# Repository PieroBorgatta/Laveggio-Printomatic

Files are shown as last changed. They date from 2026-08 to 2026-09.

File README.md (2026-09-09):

<p align="center">
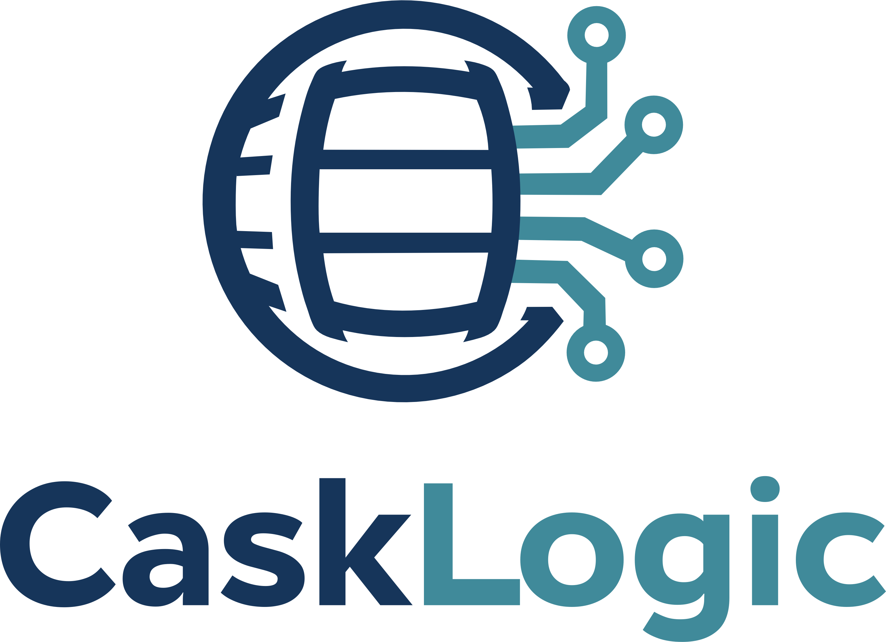
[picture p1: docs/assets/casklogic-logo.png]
CaskLogic
  
</p>

<h1 align="center">CaskLogic PesaLink</h1>

<p align="center">
  Digitalizzazione non invasiva della pesa meccanica Laveggio Printomatic del 1965.<br>
  Sistema non fiscale, destinato esclusivamente all'uso interno.
</p>

<p align="center">
  
  
  
  
</p>

<p align="center">
  <a href="#-panoramica">Panoramica</a> ·
  <a href="#-funzioni">Funzioni</a> ·
  <a href="#-calibrazione-guidata">Calibrazione</a> ·
  <a href="#-hardware">Hardware</a> ·
  <a href="#-avvio-rapido">Avvio rapido</a> ·
  <a href="#-sicurezza">Sicurezza</a> ·
  <a href="#-documentazione">Documentazione</a>
</p>

---

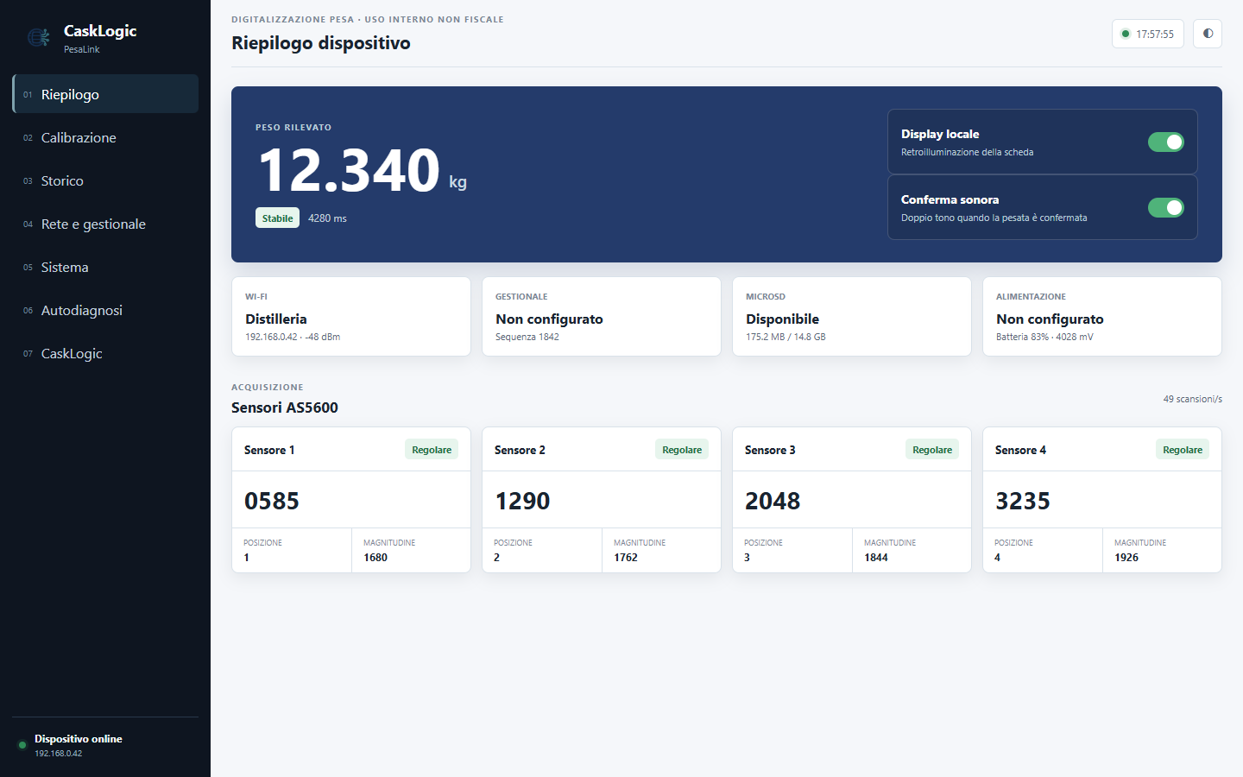
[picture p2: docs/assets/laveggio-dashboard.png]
Dashboard CaskLogic PesaLink per la pesa Laveggio Printomatic


## 🧭 Panoramica

CaskLogic PesaLink legge le quattro manopole meccaniche della pesa Laveggio
Printomatic attraverso sensori magnetici AS5600, ricostruisce il peso e conserva lo storico su
microSD. La Waveshare ESP32-S3-Touch-LCD-2.8 espone un display capacitivo
240×320 e un portale web CaskLogic per
calibrazione, diagnostica, manutenzione e integrazione con il gestionale.

Il sistema non altera la meccanica originale e mantiene sempre disponibile la
lettura locale. Il gestionale CaskLogic rimane un componente separato: questo
repository contiene firmware, simulatore, contratto di integrazione e
documentazione hardware.

> [!WARNING]
> **Digitalizzazione della pesa a uso interno, non fiscale.** Il peso acquisito
> ha finalità informative e operative interne; non sostituisce uno strumento di
> pesatura omologato né una misura valida per transazioni commerciali, adempimenti
> fiscali o verifiche metrologiche legali.

> [!IMPORTANT]
> La versione 2.2.7 mantiene acquisizione e invio prioritario separati dalle
> funzioni accessorie, include il collaudo completo della bascula e ordina i
> grafici cronologicamente. Uptime, temperature CPU e QMI8658 e frequenza CPU fissa
> sono visibili nella pagina Sistema. La rilevazione della chiusura resta configurabile e parte
> disattivata, ma è stata collaudata sul montaggio installato.

## Novità 2.2.7

- Grafici diagnostici ordinati dal campione più vecchio a sinistra al più recente a destra.
- Uptime, istante di avvio, temperatura interna della CPU e temperatura del QMI8658 evidenziati nella pagina Sistema.
- Frequenza CPU nuovamente fissa a 240 MHz; rimossi selettore, endpoint e preferenza dei profili ridotti.
- Export completo dei log eseguito in un task a bassa priorità e trasferito a blocchi, senza trattenere il portale.
- Storico iniziale ridotto alle cinque pesate più recenti e lettura della coda SD limitata a 32 KB.
- Riavvio programmabile, disattivabile, giornaliero oppure settimanale con giorno e ora configurabili.
- Interfaccia e documentazione allineate al collaudo completato dell'impianto.

## Novità 2.1.3

- Il conto alla rovescia del ripristino riattiva sempre controller LCD e retroilluminazione, anche con display spento manualmente o per inattività.
- Il ripristino di fabbrica a 10 secondi è disponibile esclusivamente con BOOT.
- Il tasto alimentazione PWR gestisce esclusivamente lo spegnimento, senza conto alla rovescia né funzione di ripristino.

## Novità 2.1.1

- Il portale di prima configurazione resta attivo mentre il dispositivo prova la rete scelta, senza riavvio immediato.
- Rilevamento captive portal per iPhone, Android e Windows; scansione iniziale più breve e nessun channel hopping durante l'uso dell'AP.
- Spegnimento completo del display configurabile dopo un numero di minuti, con riattivazione tramite touch o BOOT.
- Campi data dello storico contenuti correttamente nella larghezza disponibile su smartphone.
- Riavvio manuale da interfaccia web verificato tramite test automatico.

## Novità 2.1.0

- Letture nominali a 50 Hz su task dedicato; HTTPS e MQTT delle pesate separati da portale, storico e heartbeat.
- RTC UTC per riavvii senza rete, dopo la prima sincronizzazione; origine dell'ora esplicita.
- Stati distinti: lettura stabile, salvataggio SD, ricezione HTTPS e pubblicazione MQTT.
- Ordine dei sensori configurabile, controlli di rumore e sovrapposizione, calibrazione NVS con revisione e CRC.
- Rilevazione collaudata di colpo/quiete per la chiusura della bascula: soglie, tempi e modalità di sola osservazione.
- Luminosità, attenuazione, avvisi batteria e gestione del tasto di alimentazione.

[Guida completa, impostazioni e procedura di prova](docs/reliability-2.1.md).

## ✦ Funzioni

| Area | Funzioni disponibili |
| --- | --- |
| **Acquisizione** | Quattro AS5600 isolati tramite PCA9546/TCA9546A, calibrazione di dieci posizioni per manopola, tolleranza, isteresi e stabilità |
| **Interfacce** | Display e portale con la stessa palette interna blu `#243b6b`, fondo `#f5f7fa`, pannelli bianchi e testo antracite; boot di 10 secondi con logo centrale e barra; aggiornamenti live incrementali |
| **Storico** | Prime 5 pesate al caricamento, export coerente con i filtri, file NDJSON settimanali e retention configurabile su microSD FAT32, incluse SDXC da 128 GB |
| **Autodiagnosi** | Test di sensori, microSD, batteria, touch, speaker, IMU, RTC, Wi-Fi, DNS, gestionale e heap; grafici 24 ore e contatori di errore |
| **Audio** | Doppio tono asincrono su PCM5101 dopo il salvataggio SD di una nuova pesata; avviso distinto per errori, disabilitabile e persistente; volume 0–100% regolabile dal portale; il test web emette un singolo bip breve, azzera il DMA e disattiva fisicamente le linee I2S |
| **Assistenza** | Pacchetto ZIP anonimizzato con stato, diagnostica, log e registro aggiornamenti |
| **Rete** | DHCP o IP statico, scansione Wi-Fi e access point captive stabile `LP-PW_casklogic-192_168_4_1` |
| **Integrazione** | HTTPS/mTLS, MQTT TLS opzionale, heartbeat, eventi firmati HMAC-SHA256, metriche Prometheus e configurazione remota versionata |
| **Aggiornamenti** | OTA firmato ECDSA-P256, doppia partizione, validazione al riavvio, rollback e registro degli esiti |

Il firmware non usa una coda persistente per gli eventi verso il gestionale e
non trasforma la microSD in un NAS.

## 🖥️ Pagine del portale

| Pagina | Cosa permette di fare |
| --- | --- |
| **Riepilogo** | Leggere peso, stabilità, sensori, Wi-Fi, microSD, alimentazione e batteria. Display e conferma sonora hanno interruttori indipendenti e persistenti; il volume 0–100% vale sia per la conferma sia per `Prova bip`. |
| **Calibrazione** | Associare a ciascuna manopola le dieci posizioni `0–9`, salvare il valore magnetico e regolare moltiplicatore, tolleranza e isteresi senza ricompilare il firmware. |
| **Storico** | Consultare soltanto le 20 pesate più recenti al primo accesso, filtrare e ordinare ogni colonna ed esportare esattamente il risultato dei filtri attivi. |
| **Rete e gestionale** | Cercare reti Wi-Fi, scegliere DHCP o IP statico, configurare HTTPS/mTLS, HMAC, heartbeat, MQTT TLS e sincronizzazione controllata dal gestionale. |
| **Sistema** | Gestire display, speaker, NTP/RTC, credenziali, retention, batteria, log, riavvio e OTA firmato. Swipe e barra touch cambiano pagina; BOOT breve resta disponibile e la pressione continua mostra il ripristino da 10 secondi. |
| **Autodiagnosi** | Eseguire prove attive, controllare errori e magneti dei sensori, osservare i grafici giornalieri e scaricare un pacchetto assistenza anonimizzato. |
| **CaskLogic** | Consultare contatti di assistenza, titolarità, crediti, versione e informazioni legali del dispositivo. |

## 🎛️ Calibrazione guidata

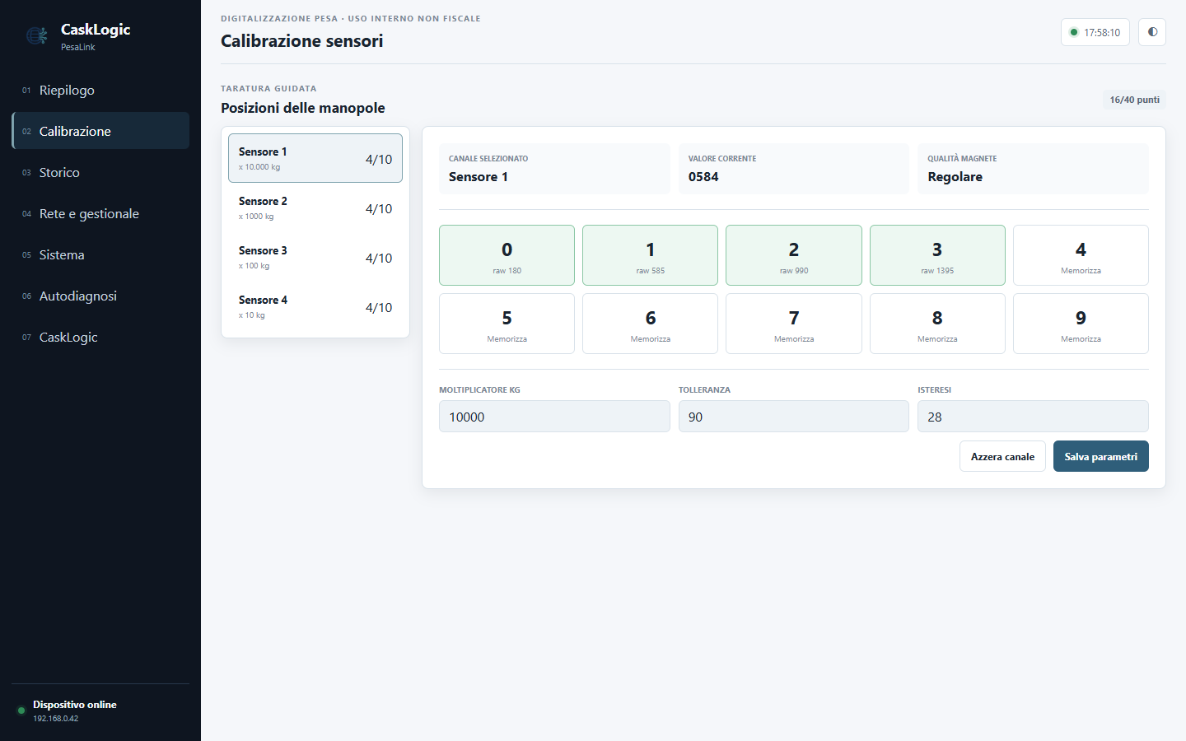
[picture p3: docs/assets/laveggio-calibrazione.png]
Calibrazione dei quattro sensori


Ogni sensore rappresenta una cifra della pesa. I quattro moltiplicatori
collaudati sono `10.000`, `1.000`, `100` e `10 kg`.

### Procedura

1. Selezionare il sensore corrispondente alla manopola da calibrare.
2. Portare fisicamente la manopola sulla cifra `0`.
3. Verificare che **Qualità magnete** indichi `Regolare` e che il valore corrente
   sia stabile.
4. Premere il riquadro `0 · Memorizza`: il firmware salva in NVS il valore
   grezzo AS5600 letto in quell'istante.
5. Ripetere la stessa operazione per le posizioni da `1` a `9`.
6. Impostare moltiplicatore, tolleranza e isteresi, quindi premere
   **Salva parametri**.
7. Ripetere la procedura per tutti e quattro i sensori, fino a raggiungere
   `40/40 punti`.

Un singolo punto può essere rimemorizzato in qualsiasi momento cliccando di
nuovo la relativa cifra. **Azzera canale** elimina soltanto i dieci punti del
sensore selezionato e richiede conferma; non modifica gli altri canali.

| Parametro | Effetto |
| --- | --- |
| **Moltiplicatore kg** | Determina il contributo della cifra al peso totale: `posizione × moltiplicatore`. |
| **Tolleranza** | Distanza angolare massima tra lettura corrente e punto memorizzato affinché la cifra sia considerata valida. |
| **Isteresi** | Mantiene la posizione precedente entro una fascia aggiuntiva, evitando passaggi continui fra due cifre causati da vibrazioni o gioco meccanico. |
| **Finestra di stabilità** | Tempo durante il quale tutte le cifre devono restare invariate prima che la misura diventi una nuova pesata stabile. |

Il confronto usa la distanza circolare dell'AS5600, quindi gestisce
correttamente anche il passaggio fra `4095` e `0`. Se un magnete è assente,
troppo debole, troppo forte, fuori tolleranza o non calibrato, l'intera misura
rimane non valida e non viene registrata come nuova pesata.

## ⚙️ Dalla lettura alla pesata

1. Il multiplexer interroga continuamente i quattro AS5600 a `100 kHz`.
2. Ogni valore grezzo viene confrontato con i dieci punti del proprio canale.
3. Tolleranza e isteresi determinano la cifra riconosciuta senza oscillazioni.
4. Le quattro cifre vengono moltiplicate e sommate per ottenere i chilogrammi.
5. La combinazione deve restare invariata per la finestra di stabilità.
6. Una combinazione valida, stabile e diversa dalla precedente genera una
   nuova riga nello storico e un evento firmato verso il gestionale. Una chiusura rilevata può aggiungere un evento di completamento.

La microSD conserva lo storico indipendentemente dalla connessione di rete, ma
non viene usata come coda automatica di reinvio.

## 📊 Autodiagnosi

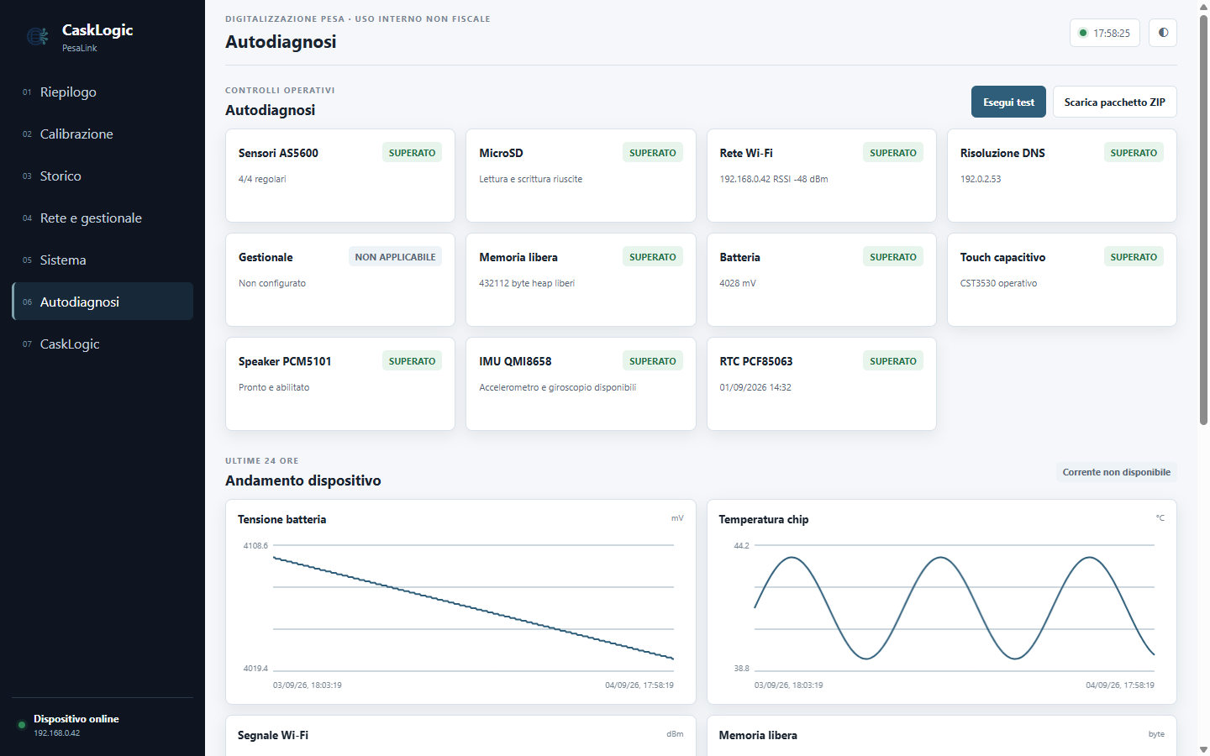
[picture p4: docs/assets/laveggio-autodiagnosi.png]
Autodiagnosi CaskLogic PesaLink


La corrente assorbita è indicata come non disponibile perché la scheda non
integra un sensore amperometrico. Tensione batteria, temperatura della scheda,
RSSI e memoria libera sono invece registrabili senza aggiungere altre schede.

## 🧩 Architettura

```mermaid
flowchart LR
    A[4 manopole] --> B[4 sensori AS5600]
    B --> C[PCA9546 Adafruit 5663]
    C --> D[ESP32-S3 Touch LCD 2.8]
    D --> E[ST7789 + CST3530/CST328]
    D --> F[MicroSD SDMMC]
    D --> G[Portale web CaskLogic]
    D -->|HTTPS / mTLS| H[Gestionale]
    D -->|MQTT TLS opzionale| H
    I[LiPo 1S] --> D
    D --> K[PCM5101 + 2 speaker]
    D --> L[QMI8658 + PCF85063]
    M[Antenna Wi-Fi 2,4 GHz] -->|SMA + pigtail IPEX1| D
```

## 🔩 Hardware

| Componente | Quantità | Riferimento |
| --- | ---: | --- |
| Waveshare ESP32-S3-Touch-LCD-2.8, 16 MB flash / 8 MB PSRAM | 1 | [Documentazione ufficiale](https://docs.waveshare.com/ESP32-S3-Touch-LCD-2.8) |
| Adafruit PCA9546 compatto a 4 canali, cod. 5663 (compatibile TCA9546A) | 1 | [Amazon.it · B0BSF13WD7](https://www.amazon.it/dp/B0BSF13WD7) |
| Kit moduli AS5600 a 12 bit con magneti | 1 kit | [Amazon.it · B0FH1Y3GLG](https://www.amazon.it/dp/B0FH1Y3GLG) |
| Cavetti micro JST-SH 1,0 mm, 4 pin | 1 confezione | [Amazon.it · B0BNCHC5Q4](https://www.amazon.it/dp/B0BNCHC5Q4) |
| Pigtail IPEX-1/U.FL verso SMA femmina, 15 cm | 1 confezione da 5 | [Amazon.it · B07YBYMBSV](https://www.amazon.it/dp/B07YBYMBSV) |
| Antenna Wi-Fi 2,4 GHz 2 dBi, SMA maschio | 1 confezione da 2 | [Amazon.it · B0CR5JPMNX](https://www.amazon.it/dp/B0CR5JPMNX) |
| Cavo dati Lapp LiYY 4 × 0,14 mm², nero | 1 spezzone da 10 m | [Amazon.it · B0C69CJYZT](https://www.amazon.it/dp/B0C69CJYZT) |
| Kit viti a macchina svasate nere M2 / M2,5 / M3, acciaio al carbonio | 1 kit da 500 | [Amazon.it · B0D1N4D5ZR](https://www.amazon.it/dp/B0D1N4D5ZR) |
| Kit da 360 inserti filettati a caldo in ottone M2 / M2,5 / M3 / M4 / M5 / M6 | 1 kit | [Amazon.it · B0G1H5QBSF](https://www.amazon.it/dp/B0G1H5QBSF); utilizzati 8 inserti M5 × 6 mm |
| Grani con punta M5 × 12 mm, acciaio inox A2, esagono incassato, DIN 914 / ISO 4027 | 8 (2 per supporto) | [Amazon.it · B0BZD8WXDQ](https://www.amazon.it/dp/B0BZD8WXDQ); confezione da 20 |
| Speaker 8 Ω 2 W 2030 | 2 | Inclusi con la scheda Waveshare |
| Batteria LiPo 803040, 3,7 V, 1000 mAh, protetta | 1 | [Amazon.it · B0G5NM9YJ4](https://www.amazon.it/dp/B0G5NM9YJ4); connettore JST 1,25 mm, polarità da verificare |
| SanDisk Extreme microSDXC 128 GB, A2 / U3 / V30 | 1 | [Amazon.it · B07FCMKK5X](https://www.amazon.it/dp/B07FCMKK5X); montata e verificata in lettura/scrittura |

Ciascuno dei quattro supporti dei sensori AS5600 utilizza due inserti
filettati a caldo M5 × 6 mm e due grani con punta M5 × 12 mm. Il montaggio
completo impiega otto inserti e otto grani.

### Foto del prototipo

<p align="center">
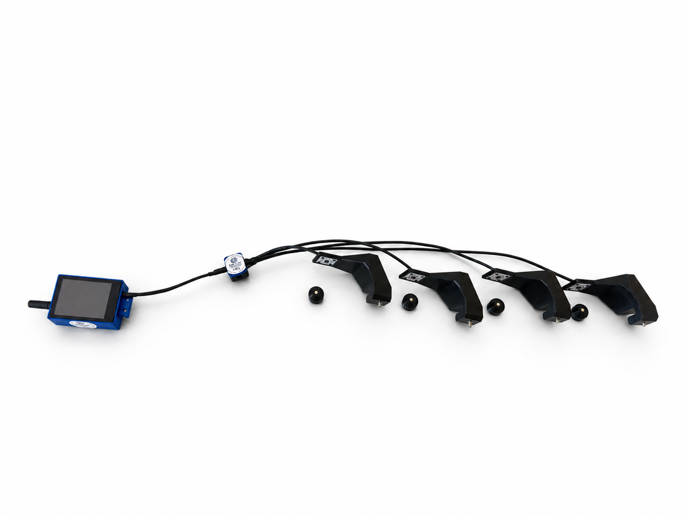
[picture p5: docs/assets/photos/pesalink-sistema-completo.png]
Sistema CaskLogic PesaLink completo
  
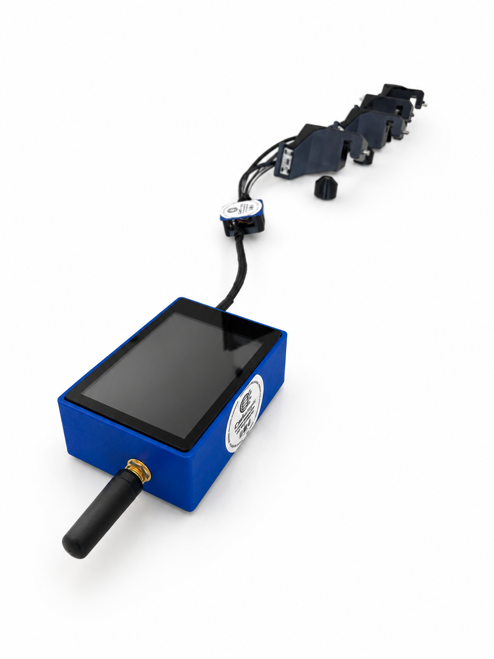
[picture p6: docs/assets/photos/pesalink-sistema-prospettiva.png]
Sistema PesaLink in prospettiva
  
</p>
<p align="center">
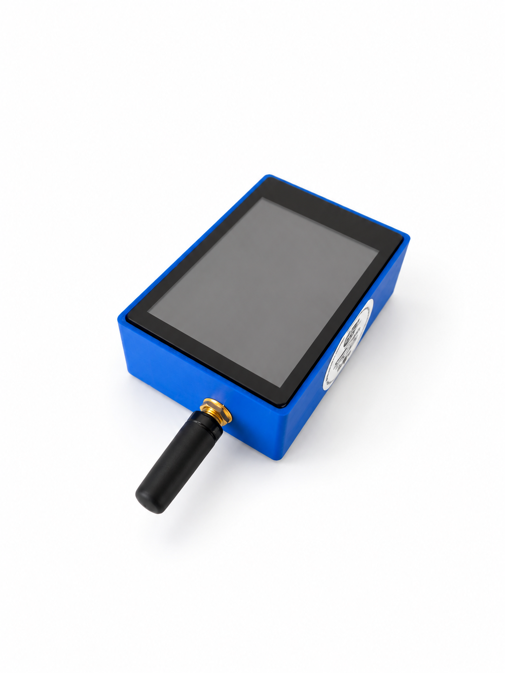
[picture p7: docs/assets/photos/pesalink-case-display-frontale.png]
Case del display visto frontalmente
  
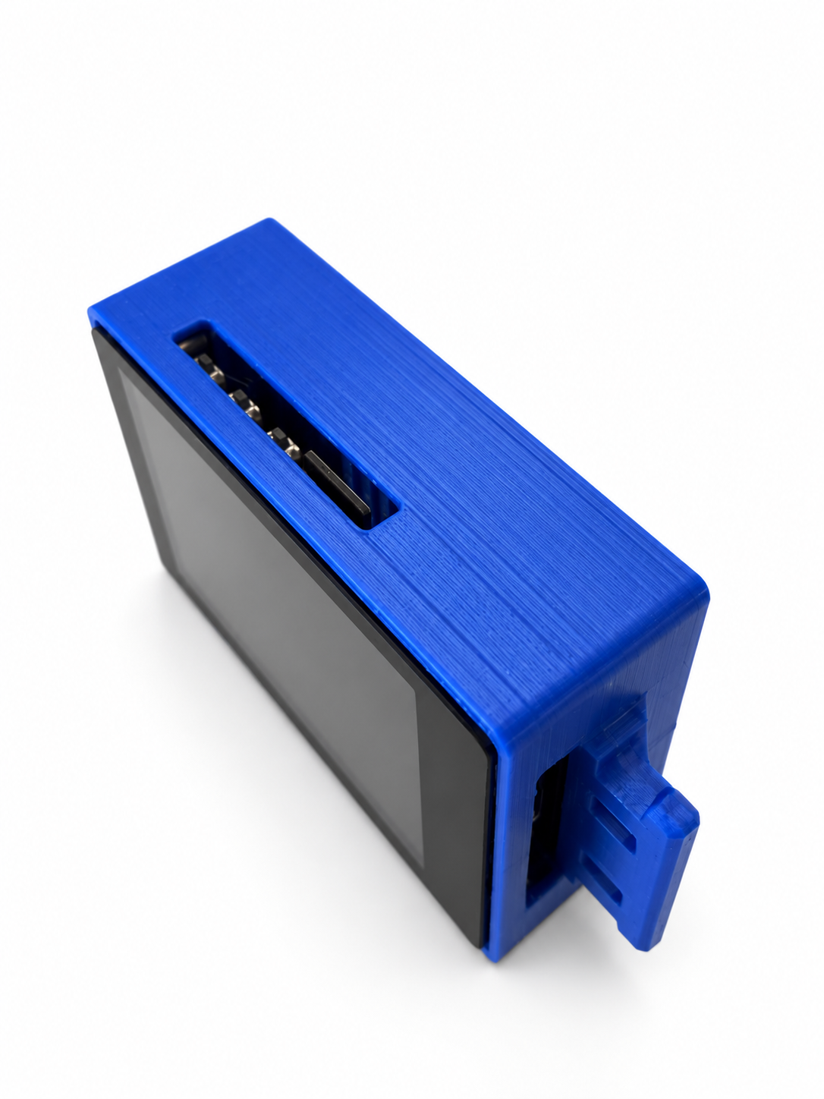
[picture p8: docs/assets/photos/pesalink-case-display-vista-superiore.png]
Case del display visto dall'alto
  
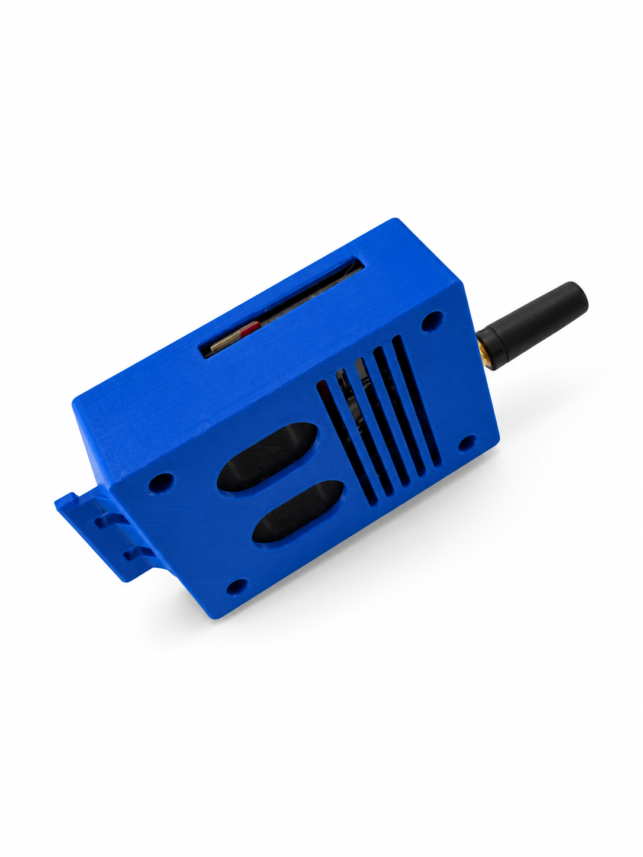
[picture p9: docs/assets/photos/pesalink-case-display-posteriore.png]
Case del display visto posteriormente
  
</p>
<p align="center">
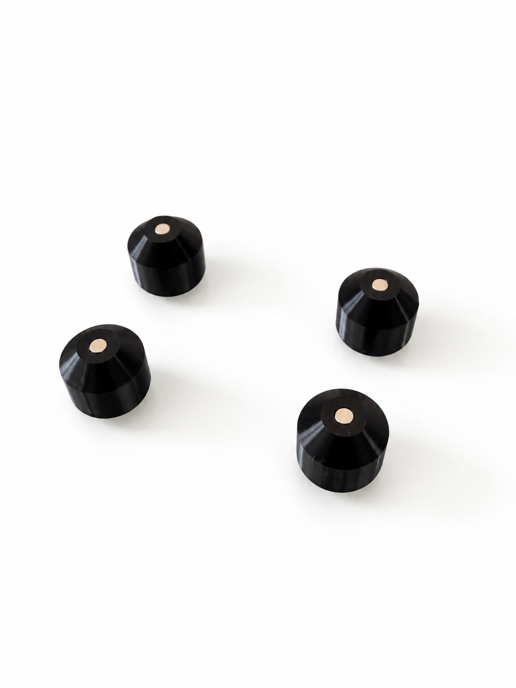
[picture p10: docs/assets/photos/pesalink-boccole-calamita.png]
Boccole stampate per le calamite
  
</p>

### Foto dell'installazione completata

<p align="center">
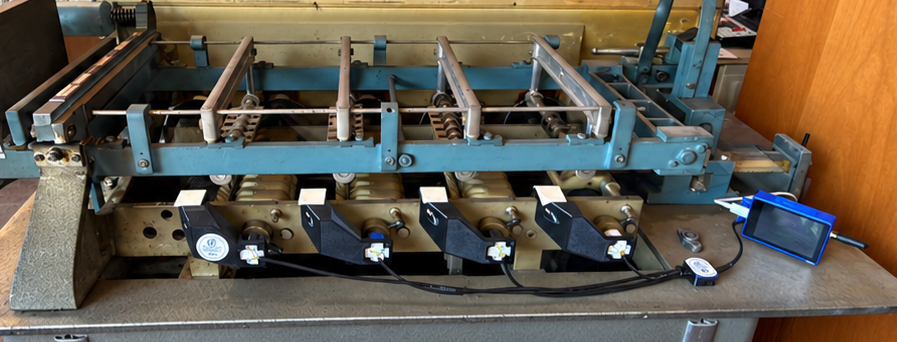
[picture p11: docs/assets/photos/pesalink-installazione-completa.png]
Installazione completa dei quattro sensori PesaLink e del gateway sulla bascula
  
</p>
<p align="center">
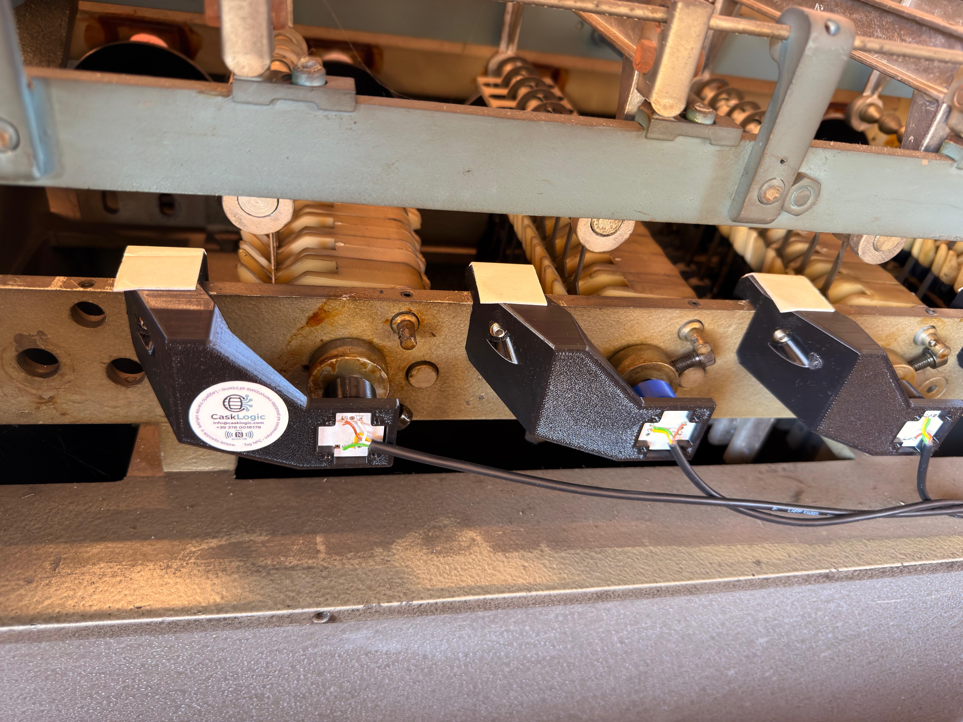
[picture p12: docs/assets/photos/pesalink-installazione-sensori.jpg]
Dettaglio dei supporti e dei sensori PesaLink installati sulla bascula
  
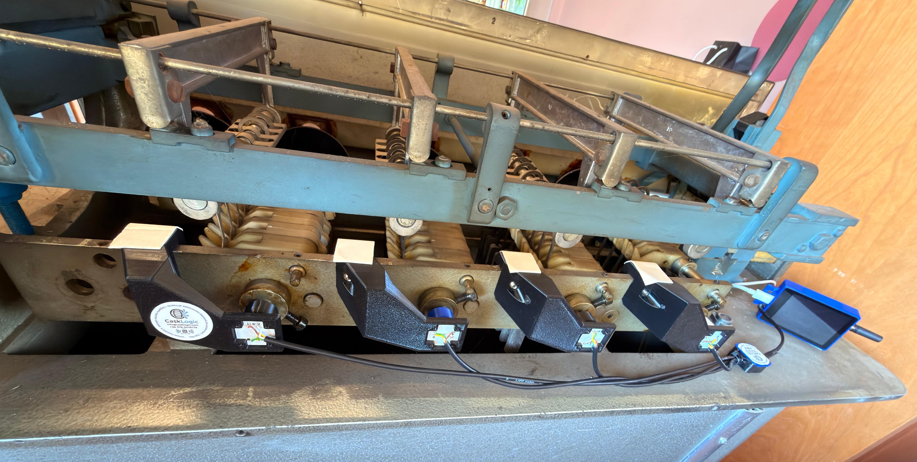
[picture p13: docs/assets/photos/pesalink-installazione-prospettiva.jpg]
Installazione PesaLink vista in prospettiva con quattro sensori e display
  
</p>

I file pronti per la stampa, compreso il progetto Bambu Studio, sono raccolti
in [`stl/original-designs`](stl/original-designs/). Il progetto completo è
disponibile anche su [MakerWorld](https://makerworld.com/it/models/3269009-pesalink#profileId-3706531).

### Timelapse della stampa 3D

- [Realizzazione dei supporti per i sensori AS5600](docs/videos/timelapse-supporti-sensori.mp4) — 16 s, MP4 720p
- [Realizzazione dei supporti per i magneti](docs/videos/timelapse-supporti-magneti.mp4) — 6 s, MP4 720p
- [Realizzazione della scatola ESP32](docs/videos/timelapse-scatola-esp32.mp4) — 8 s, MP4 720p

La nuova Waveshare integra gestione di carica, misura batteria, RTC, IMU,
codec PCM5101, amplificatore e slot microSD. Collegamenti e verifiche sono
descritti in [`docs/power-and-ups.md`](docs/power-and-ups.md).

Il PCA9546 cod. 5663 sostituisce il precedente modello STEMMA QT cod. 5664:
richiede intestazioni o fili saldati e non è compatibile con il relativo case
STL. Per attivare il connettore IPEX1 dell'antenna esterna è stato necessario
spostare a sinistra la resistenza di selezione RF. La modifica è stata eseguita
a scheda disalimentata, con saldatore ad aria calda e flussante: il solo
collegamento del pigtail non attiva l'antenna esterna. La foto e la procedura
sono riportate in [`docs/wiring.md`](docs/wiring.md#antenna-wi-fi-esterna).

## 🚀 Avvio rapido

### Simulatore web

```powershell
cd firmware/production-gateway
npm test
npm run simulate
```

Il portale risponde su `http://127.0.0.1:4177`. Il simulatore usa gli stessi
file HTML, CSS e JavaScript incorporati nel firmware.

### Build ESP32-S3

```powershell
cd firmware/production-gateway
$env:PLATFORMIO_CORE_DIR = 'C:\pio'
py -m platformio run
```

| Risorsa | Utilizzo verificato |
| --- | ---: |
| RAM statica | Vedere i risultati della build 2.1 in `docs/test-results.md` |
| Flash applicazione | Vedere i risultati della build 2.1 in `docs/test-results.md` |
| Profili compilati | V2 `CST3530` e V1 `CST328`, entrambi con autodetect di fallback |
| Slot OTA | `6 MiB` ciascuno su flash da 16 MB |

Artefatti principali:

- `firmware.signed.bin`: aggiornamento accettato dal portale OTA;
- `firmware.factory.bin`: prima installazione completa, inclusa la tabella
  partizioni;
- `firmware.bin`: input non firmato, non caricabile dal portale.

## 🛡️ Sicurezza

<p>
  
  
  
  
</p>

- autenticazione HTTP Basic, rate limit, CSRF e header browser restrittivi;
- endpoint remoti esclusivamente TLS con CA obbligatoria e mTLS opzionale;
- segreto HMAC distinto per la firma delle pesate;
- token dedicato per `GET /api/metrics`;
- configurazione remota limitata a una whitelist di campi operativi;
- chiave privata OTA esterna al repository;
- pacchetto assistenza senza credenziali, SSID o indirizzi IP.

Il portale locale usa HTTP e deve restare su una VLAN tecnica, senza port
forwarding verso Internet. Secure Boot e Flash Encryption tramite eFuse
richiedono provisioning fisico irreversibile su ciascuna scheda. Dettagli in
[`docs/security.md`](docs/security.md) e
[`docs/firmware-signing.md`](docs/firmware-signing.md).

## 🗂️ Struttura

| Percorso | Contenuto |
| --- | --- |
| [`firmware/production-gateway`](firmware/production-gateway/) | Gateway operativo ESP32-S3 touch e simulatore web |
| [`firmware/calibration-reader`](firmware/calibration-reader/) | Firmware diagnostico usato nelle prime prove hardware |
| [`docs`](docs/) | Cablaggio, alimentazione, sicurezza, test e contratto gestionale |
| [`stl`](stl/) | Case e supporti stampabili in 3D con licenze separate |

## 📚 Documentazione

- [Hardware e distinta materiali](docs/hardware.md)
- [Cablaggio dei sensori](docs/wiring.md)
- [Batteria e alimentazione della nuova scheda](docs/power-and-ups.md)
- [Collaudo hardware al ricevimento](docs/friday-hardware-validation.md)
- [Architettura operativa](docs/production-architecture.md)
- [Sicurezza del gateway](docs/security.md)
- [Firma e rilascio firmware](docs/firmware-signing.md)
- [Contratto futuro con CaskLogic](docs/casklogic-integration-contract.md)
- [Prompt per implementare il lato gestionale](docs/casklogic-integration-prompt.md)
- [Risultati delle verifiche](docs/test-results.md)

## Stato del progetto

**Progetto completato:** installazione, calibrazione, collaudo hardware e integrazione con CaskLogic conclusi.

- [x] Lettura AS5600 e multiplexer verificata sul prototipo
- [x] Gateway, portale web e simulatore implementati
- [x] Test host `38/38`, verifica browser e build ESP32-S3 V2/V1 completati
- [x] Doppia partizione OTA da 6 MiB e firma ECDSA generate per entrambi i profili
- [x] Collaudo completo del display, touch, due speaker, RTC in blackout, IMU sulla bascula e batteria
- [x] Calibrazione meccanica completa delle quattro manopole
- [x] MicroSD SanDisk Extreme 128 GB montata e verificata in lettura/scrittura
- [x] Collaudo di batteria, commutazione e rollback forzato
- [x] Contratto implementato e integrato nel gestionale CaskLogic

## Licenza e attribuzioni

Il codice e la documentazione sono distribuiti con licenza
[Creative Commons Attribution 4.0 International](LICENSE), salvo indicazioni
diverse nei singoli file. È richiesta l'attribuzione a **Piero Borgatta** e ai
contributori del progetto.

Gli STL di terzi mantengono licenza e attribuzione originali, documentate in
[`THIRD_PARTY_NOTICES.md`](THIRD_PARTY_NOTICES.md).

<p align="center">
  <strong>CaskLogic Solutions</strong><br>
  CaskLogic PesaLink · preservare la meccanica, rendere misurabile il dato
</p>

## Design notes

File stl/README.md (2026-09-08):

# Modelli per stampa 3D

Questa cartella contiene le parti meccaniche stampabili del progetto.

## Organizzazione

- [`third-party/`](third-party/): modelli provenienti da piattaforme o autori
  esterni. Ogni modello mantiene attribuzione, link e licenza originali.
- [`original-designs/`](original-designs/): modelli progettati da Piero Borgatta
  per CaskLogic PesaLink e la pesa Laveggio Printomatic.

Non assumere che tutti gli STL abbiano la stessa licenza. Controllare sempre il
README e il file `LICENSE` presenti nella cartella specifica del modello.

## Modelli previsti

| Parte | Provenienza | Stato |
| --- | --- | --- |
| Case multiplexer Adafruit PCA9546 STEMMA QT cod. 5664 | OpenSensor.io / Printables | STL inclusi come archivio; non compatibile con il nuovo 5663 compatto |
| Case multiplexer Adafruit PCA9546 compatto cod. 5663 | Progetto originale | Da progettare |
| Case Waveshare ESP32-S3-Touch-LCD-2.8 | Progetto originale | STL e progetto Bambu Studio disponibili |
| Supporti AS5600 | Progetto originale | STL e progetto Bambu Studio disponibili |
| Supporti magneti | Progetto originale | STL e progetto Bambu Studio disponibili |

Il progetto completo è pubblicato su
[MakerWorld · PesaLink](https://makerworld.com/it/models/3269009-pesalink#profileId-3706531).

## Timelapse di realizzazione

- [Supporti per i sensori AS5600](../docs/videos/timelapse-supporti-sensori.mp4)
- [Supporti per i magneti](../docs/videos/timelapse-supporti-magneti.mp4)
- [Scatola ESP32](../docs/videos/timelapse-scatola-esp32.mp4)

Ogni supporto stampato per un sensore AS5600 utilizza due inserti filettati a
caldo M5 × 6 mm e due grani con punta M5 × 12 mm. I quattro supporti richiedono
quindi otto inserti e otto grani complessivi. I grani in acciaio inox A2,
DIN 914 / ISO 4027, sono disponibili nella
[confezione da 20 utilizzata](https://www.amazon.it/dp/B0BZD8WXDQ).

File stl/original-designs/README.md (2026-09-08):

# Modelli originali CaskLogic PesaLink

Questa cartella è riservata ai modelli progettati da Piero Borgatta per la
pesa Laveggio Printomatic:

- case per Waveshare ESP32-S3-Touch-LCD-2.8;
- supporti per i quattro sensori AS5600;
- supporti per i magneti sulle manopole della pesa;
- eventuali staffe, passacavi e protezioni sviluppati per il montaggio finale.

## File disponibili

| File | Contenuto |
| --- | --- |
| [`pesalink-v2.3mf`](pesalink-v2.3mf) | Progetto completo per Bambu Studio, con piatti e impostazioni di stampa |
| [`esp32-s3-touch-lcd-2_8-v01.stl`](esp32-s3-touch-lcd-2_8-v01.stl) | Case per il display Waveshare ESP32-S3-Touch-LCD-2.8 |
| [`supporto-sensore.stl`](supporto-sensore.stl) | Supporto per il sensore magnetico AS5600 |
| [`boccola-calamita-v4.stl`](boccola-calamita-v4.stl) | Boccola per la calamita montata sulla manopola |

Ogni supporto per un sensore AS5600 utilizza due inserti filettati a caldo
M5 × 6 mm e due grani con punta M5 × 12 mm. Per i quattro supporti sono stati
impiegati otto inserti e otto grani. I grani sono in acciaio inox A2 con
esagono incassato, DIN 914 / ISO 4027
([Amazon.it · B0BZD8WXDQ](https://www.amazon.it/dp/B0BZD8WXDQ)).

Il progetto completo è disponibile su
[MakerWorld · PesaLink](https://makerworld.com/it/models/3269009-pesalink#profileId-3706531).
La licenza dei modelli originali è indicata nella relativa pagina MakerWorld.

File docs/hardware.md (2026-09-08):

# Hardware

## Distinta materiali aggiornata

| Componente | Quantità | Riferimento |
| --- | ---: | --- |
| Waveshare ESP32-S3-Touch-LCD-2.8, 16 MB flash / 8 MB PSRAM | 1 | [Documentazione ufficiale](https://docs.waveshare.com/ESP32-S3-Touch-LCD-2.8) |
| Adafruit PCA9546 compatto a 4 canali, cod. 5663 (compatibile TCA9546A) | 1 | [Amazon.it - B0BSF13WD7](https://www.amazon.it/dp/B0BSF13WD7) |
| Kit con 4 moduli AS5600 a 12 bit e magneti | 1 | [Amazon.it - B0FH1Y3GLG](https://www.amazon.it/dp/B0FH1Y3GLG) |
| Cavetti micro JST-SH 1,0 mm a 4 pin | 1 confezione | [Amazon.it - B0BNCHC5Q4](https://www.amazon.it/dp/B0BNCHC5Q4) |
| Pigtail IPEX-1/U.FL verso SMA femmina, 15 cm | 1 confezione da 5 | [Amazon.it - B07YBYMBSV](https://www.amazon.it/dp/B07YBYMBSV) |
| Antenna Wi-Fi 2,4 GHz 2 dBi, SMA maschio | 1 confezione da 2 | [Amazon.it - B0CR5JPMNX](https://www.amazon.it/dp/B0CR5JPMNX) |
| Cavo dati Lapp LiYY 4 x 0,14 mm2, nero | 1 spezzone da 10 m | [Amazon.it - B0C69CJYZT](https://www.amazon.it/dp/B0C69CJYZT) |
| Kit viti a macchina svasate nere M2 / M2,5 / M3, acciaio al carbonio | 1 kit da 500 | [Amazon.it - B0D1N4D5ZR](https://www.amazon.it/dp/B0D1N4D5ZR) |
| Kit da 360 inserti filettati a caldo in ottone M2 / M2,5 / M3 / M4 / M5 / M6 | 1 kit | [Amazon.it - B0G1H5QBSF](https://www.amazon.it/dp/B0G1H5QBSF); utilizzati 8 inserti M5 x 6 mm |
| Grani con punta M5 x 12 mm, acciaio inox A2, esagono incassato, DIN 914 / ISO 4027 | 8 (2 per supporto) | [Amazon.it - B0BZD8WXDQ](https://www.amazon.it/dp/B0BZD8WXDQ); confezione da 20 |
| Speaker 8 ohm 2 W 2030 | 2 | Inclusi con la Waveshare |
| Batteria LiPo 803040, 3,7 V, 1000 mAh, protetta | 1 | [Amazon.it - B0G5NM9YJ4](https://www.amazon.it/dp/B0G5NM9YJ4); 8 x 30 x 40 mm, connettore JST 1,25 mm, polarità da verificare |
| SanDisk Extreme microSDXC 128 GB, A2 / U3 / V30 | 1 | [Amazon.it - B07FCMKK5X](https://www.amazon.it/dp/B07FCMKK5X); montata e verificata in lettura/scrittura |

Le inserzioni commerciali possono cambiare: prima di alimentare verificare
sempre serigrafia, tensione, connettore e polarità del componente ricevuto.

## Destinazione d'uso

CaskLogic PesaLink digitalizza la pesa meccanica Laveggio Printomatic per uso
esclusivamente interno e non fiscale. Il peso acquisito ha finalità informative
e operative: non sostituisce uno strumento omologato e non è valido per
transazioni commerciali, adempimenti fiscali o verifiche metrologiche legali.

## Waveshare ESP32-S3-Touch-LCD-2.8

La scheda riunisce ESP32-S3, LCD ST7789 verticale 240x320, touch capacitivo,
slot microSD SD_MMC, audio PCM5101 con amplificatore, IMU QMI8658, RTC PCF85063,
gestione LiPo e misura della batteria su GPIO8. Il firmware riconosce entrambi i
controller touch documentati:

- revisione V2: CST3530;
- revisione V1: CST328.

Waveshare indica che la V1 è stata sostituita dalla V2; verificare la revisione
stampata sulla scheda prima del primo flash. I due profili compilati differiscono
solo nella preferenza iniziale del touch e mantengono un rilevamento di fallback.

La scheda dispone di antenna ceramica integrata e connettore IPEX1. Per usare il
pigtail IPEX-1/U.FL verso SMA e l'antenna esterna da 2,4 GHz occorre spostare la
resistenza di selezione RF. Sul montaggio realizzato la resistenza è stata
spostata a sinistra con saldatore ad aria calda e flussante, lavorando a scheda
disalimentata. Non forzare il connettore IPEX1. La posizione precedente e la
direzione dello spostamento sono illustrate in [cablaggio](wiring.md#antenna-wi-fi-esterna).

## Multiplexer e sensori

Il PCA9546 Adafruit cod. 5663 isola quattro rami I2C, necessario perché tutti gli
AS5600 usano l'indirizzo `0x36`. È compatibile con il TCA9546A usato dal firmware,
risponde normalmente a `0x70` e può essere configurato da `0x70` a `0x77`. Il bus
esterno della nuova scheda usa GPIO11 SDA e GPIO10 SCL a 100 kHz.

Questo modello compatto sostituisce il precedente STEMMA QT cod. 5664. Viene
fornito come PCB assemblato senza cavi o sensori e richiede intestazioni o fili
saldati sui pin `VIN`, `GND`, `SDA`, `SCL`, `RST`, `SD0`-`SD3` e `SC0`-`SC3`.

Ogni AS5600 restituisce 0-4095 su un giro. Per la lettura I2C servono solo VCC,
GND, SDA e SCL; DIR, GPO e OUT rimangono scollegati. Il magnete deve essere
diametralmente magnetizzato, centrato e ruotare sul proprio asse. Distanza e
centraggio vanno validati con i flag MD, ML e MH e con una rotazione completa.

Il cavo Lapp LiYY 4 x 0,14 mm2 è fornito in uno spezzone da 10 m ed è composto da
quattro conduttori non schermati. Va tagliato nelle lunghezze necessarie: la
quantità acquistata non autorizza una singola tratta I2C da 10 m. Mantenere i
rami quanto più corti possibile e verificare sul montaggio reale qualità del
segnale, frequenza, pull-up e affidabilità delle scansioni.

## Fissaggio dei supporti sensore

Ciascuno dei quattro supporti dei sensori AS5600 utilizza due inserti filettati
a caldo M5 x 6 mm e due grani con punta M5 x 12 mm. Per i quattro supporti sono
stati impiegati otto inserti e otto grani. Gli inserti sono installati a caldo
nella plastica stampata; i grani DIN 914 / ISO 4027 serrano i porta-sensori.

## Alimentazione

La scheda può essere alimentata via USB-C o tramite una LiPo 1S sul connettore
dedicato. Multiplexer e sensori ricevono 3,3 V dalla scheda e condividono la
massa. La precedente scheda esterna bq25185 non è più necessaria nel cablaggio
standard: non collegarla in parallelo al caricatore integrato senza un progetto
elettrico specifico che impedisca ritorni di corrente.

Riferimenti:

- [Waveshare ESP32-S3-Touch-LCD-2.8](https://docs.waveshare.com/ESP32-S3-Touch-LCD-2.8)
- [PCA9546 Adafruit cod. 5663](https://learn.adafruit.com/adafruit-pca9546-4-channel-i2c-multiplexer/pinouts)
- [Datasheet AS5600](https://look.ams-osram.com/m/7059eac7531a86fd/original/AS5600-DS000365.pdf)

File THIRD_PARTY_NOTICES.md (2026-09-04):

# Componenti di terze parti

Questo file elenca materiali inclusi nel repository ma non creati dagli autori
di CaskLogic PesaLink. La licenza generale `CC BY 4.0` del repository non
sostituisce le rispettive licenze originali.

## Case per Adafruit PCA9546, modello Printables 658753

- Titolo originale: **Enclosure for Adafruit 4ch QT Mux 5664 PCA9546**
- Autore: **OpenSensor.io**
- Profilo Printables: `OpenSensorIO_984282`
- Fonte originale:
  <https://www.printables.com/model/658753-enclosure-for-adafruit-4ch-qt-mux-5664-pca9546/files>
- Pubblicazione originale: 25 novembre 2023
- Licenza indicata da Printables: **Creative Commons Attribution–NonCommercial–ShareAlike 4.0 International (CC BY-NC-SA 4.0)**
- Testo della licenza:
  <https://creativecommons.org/licenses/by-nc-sa/4.0/legalcode>

File inclusi senza modifiche dichiarate:

- `3d Print for Adafruit 5664 PCA9546 Stemma QT v12.stl`
- `3d Print Top for Adafruit 5664 PCA9546 v6.stl`

I file possono essere condivisi e adattati rispettando attribuzione, uso non
commerciale e condivisione allo stesso modo. Per eventuali usi commerciali è
necessaria un'autorizzazione separata del titolare dei diritti.

## Marchio CaskLogic

L'asset `firmware/production-gateway/data/casklogicmark.png` è il marchio
CaskLogic fornito dal progetto gestionale collegato ed è incluso esclusivamente
per identificare l'interfaccia del dispositivo. Il marchio non è concesso sotto
la licenza CC BY 4.0 generale del repository e rimane di proprietà del relativo
titolare.

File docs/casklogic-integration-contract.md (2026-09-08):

# Contratto CaskLogic PesaLink con Testa&Coda

Questo documento descrive il contratto implementato tra il firmware PesaLink e
il gestionale CaskLogic.

## Configurazione rapida consigliata

1. Nel gestionale aprire **Amministrazione → Configurazione → PesaLink**.
2. Abilitare PesaLink e **Ricezione HTTPS**, quindi aggiungere il lettore usando
   l'ID mostrato nel portale ESP32.
3. Nella finestra delle credenziali scaricare **Configurazione ESP32**. Il file
   contiene endpoint, token, segreto HMAC e la CA pubblica necessaria a
   verificare il server; non contiene la chiave privata della CA.
4. Nel portale locale del lettore aprire **Rete e gestionale**, premere
   **Importa configurazione CaskLogic**, scegliere il file e infine premere
   **Salva integrazione**.

Gli endpoint di produzione sono:

```text
Eventi:        https://testa-coda.distilleriabeccaris.it/api/v1/scale-devices/events
Configurazione:https://testa-coda.distilleriabeccaris.it/api/v1/scale-devices/config
```

HTTPS è sufficiente per invio, ricevuta applicativa e sincronizzazione della
configurazione. MQTT/TLS è un canale opzionale per stato realtime e comandi:
richiede un broker configurato e credenziali del broker distinte dal token
HTTPS. Se la password MQTT non compare nel file, va inserita manualmente nel
portale ESP32.

## Endpoint dispositivo

Proposta:

```text
POST /api/v1/scale-devices/events
Authorization: Bearer <token univoco del dispositivo>
Content-Type: application/json
```

Il trasporto deve usare TLS con un certificato server verificabile dalla CA
installata sul dispositivo. Quando viene configurato mTLS, il reverse proxy o
il backend deve inoltre verificare il certificato client e associarlo allo
stesso `device_id` autorizzato dal token applicativo.

Eventi inviati:

- `scale.snapshot`: misura valida e stabile cambiata;
- `scale.heartbeat`: ultima misura completa durante inattività;
- `device.power`: perdita o ripristino dell'alimentazione esterna.

Campi di identità e ordinamento obbligatori:

```json
{
  "type": "scale.snapshot",
  "schema_version": 1,
  "event_id": "pesalink-01:A1B2C3-18FA93DE:1842",
  "device_id": "pesalink-01",
  "boot_id": "A1B2C3-18FA93DE",
  "sequence": 1842,
  "captured_at": "2026-08-29T16:42:18+0200",
  "captured_ms": 983442,
  "digits": [1, 2, 3, 4],
  "multipliers_kg": [10000, 1000, 100, 10],
  "weight_kg": 12340,
  "stable": true,
  "valid": true,
  "sensors": [],
  "signature_alg": "HMAC-SHA256",
  "signature": "<64 caratteri esadecimali>"
}
```

La firma copre, in quest'ordine e separati da `\n`, `event_id`, `captured_at`,
`weight_kg` e le quattro cifre unite da un punto. Esempio canonico:

```text
pesalink-01:A1B2C3-18FA93DE:1842
2026-08-29T16:42:18+0200
12340
1.2.3.4
```

Il backend deve verificare la firma prima di usare l'evento e confrontarla in
tempo costante. `event_id` e l'identificativo univoco primario; la terna
`(device_id, boot_id, sequence)` resta il vincolo di deduplicazione strutturale.

## MQTT TLS opzionale

Per lo stato realtime e preferibile MQTT TLS rispetto al polling del
dispositivo. Il firmware usa questi topic, dove `<base>` e configurabile:

```text
<base>/<device_id>/availability   retained: online/offline
<base>/<device_id>/weights        eventi scale.snapshot
<base>/<device_id>/status         retained: scale.heartbeat
<base>/<device_id>/commands       comandi gestionali
<base>/<device_id>/command-acks   esito dei comandi
```

I soli comandi ammessi sono `display.set`, `config.sync` e
`diagnostics.run`, ciascuno con `command_id`. Autenticazione broker, CA e mTLS
devono essere associati al dispositivo. Non esiste una coda persistente sul
gateway: un evento MQTT non consegnato non viene riprovato dopo la
riconnessione; lo storico locale rimane disponibile per audit ed export.

## Configurazione remota

Il dispositivo esegue un `GET` HTTPS all'URL configurato e invia
`Authorization: Bearer`, `X-Device-Id` e `X-Config-Version`. Il backend può
rispondere `304` oppure `200` con una versione strettamente crescente. Sono
accettati soltanto: finestra di stabilità, display predefinito, heartbeat e
watchdog, retention dello storico e calibrazioni. Rete Wi-Fi, amministratore,
endpoint, token e materiale TLS restano esclusivamente locali. Una risposta
valida viene salvata in NVS; errori o payload non validi lasciano attiva
l'ultima configurazione locale.

## Metriche

`GET /api/metrics` espone metriche Prometheus per uptime, heap, Wi-Fi, ora,
microSD, batteria, temperatura, integrazione, MQTT, peso e salute/errori dei
sensori. Il gestionale o il sistema di monitoraggio deve usare il Bearer token
metriche dedicato e raggiungere il dispositivo soltanto dalla VLAN tecnica.

## Regole backend

- autenticare il token confrontandone un hash, senza memorizzarlo in chiaro;
- verificare HMAC-SHA256 in tempo costante e mantenere segreti distinti per
  dispositivo;
- deduplicare per `(device_id, boot_id, sequence)`;
- rifiutare versioni schema sconosciute e payload non validi;
- mantenere l'ultima misura live separata dalle pesate confermate;
- considerare scaduta la misura dopo un timeout configurabile;
- pubblicare l'aggiornamento al kiosk tramite il canale realtime esistente;
- non creare automaticamente lordo, tara o una pesata definitiva;
- non sovrascrivere un campo mentre l'operatore sta inserendo un valore manuale;
- conservare audit di connessioni, errori e cambi di alimentazione;
- registrare ultimo heartbeat ricevuto, codice di risposta e stato online;
- rispondere rapidamente all'heartbeat prima di avviare elaborazioni non
  necessarie alla conferma, per non causare riavvii impropri del dispositivo;
- demandare al backend l'invio e-mail per gli eventi configurati.

## Risposta

Una risposta `2xx` conferma soltanto ricezione e validazione dell'evento:

```json
{
  "accepted": true,
  "device_id": "pesalink-01",
  "boot_id": "A1B2C3-18FA93DE",
  "sequence": 1842,
  "server_time": "2026-08-29T14:42:18Z"
}
```

Il dispositivo mantiene lo storico locale anche quando il backend non è
raggiungibile, ma non usa lo storico come coda di reinvio. Le rotazioni usano
file univoci, senza sovrascrivere gli
archivi precedenti, e l'interfaccia permette un export NDJSON concatenato. La
microSD non è la fonte canonica delle pesate confermate nel gestionale e il
campo locale `delivery` registra l'intenzione di invio, non una ricevuta del
backend.

Il watchdog heartbeat del dispositivo considera raggiungibile il gestionale
soltanto dopo una risposta `2xx`. Dopo la soglia configurata esegue al massimo
un riavvio e resta inibito fino a una nuova risposta valida, evitando reboot
loop durante indisponibilità prolungate del backend.

## Estensioni compatibili 2.1.0

Lo snapshot ordinario `scale.snapshot` rimane valido e stabile, inviato a ogni
nuova stabilizzazione. Il dispatcher pesate usa identificativi
`device_id:boot_id:wN`; la sequenza del flusso pesate è indipendente da quella
heartbeat. Deduplicare sempre per `event_id`, non soltanto per `sequence`.
Il client MQTT delle pesate usa un client ID con suffisso `-weights`, distinto
 dal client servizi; il topic rimane `{base}/{device_id}/weights`.

Campi aggiuntivi: `calibration_revision`, `sensor_order` (posizione logica →
canale fisico), `time_source` (`ntp`, `rtc`, `unavailable`), `time_valid`,
`closure_detected`, `closure_peak_g`, `weight_completed`,
`completion_experimental`. `time_synchronized` significa NTP riuscito in questo
avvio; un timestamp RTC può essere valido con `time_synchronized=false`.

Con rilevazione bascula disabilitata il flusso ordinario non cambia. In sola
osservazione i candidati restano locali. Se il completamento della pesata è
abilitato, una chiusura riconosciuta produce uno snapshot aggiuntivo anche a
peso invariato; `weight_completed=true` non autorizza la persistenza automatica
 di lordo/tara né sostituisce la conferma dell'operatore.

La firma HMAC storica resta invariata. Per usare il suggerimento di completamento
verificare anche `completion_signature` (HMAC-SHA256 esadecimale, stesso segreto)
sulla concatenazione UTF-8 senza newline finale:

```text
event_id + "\n" + captured_at + "\n" + weight_kg + "\n" +
digits.join(".") + "\n" + calibration_revision + "\n" +
(weight_completed ? "true" : "false")
```

Tutti i numeri sono in formato decimale. Il backend deve ignorare il suggerimento
se manca la firma aggiuntiva o non è valido, mantenendo la lettura ordinaria.
`HTTP 2xx` è la ricevuta dell'endpoint; MQTT QoS 0 non prova l'acquisizione nel DB.
Il dispositivo non implementa una coda persistente di reinvio. Le saturazioni
RAM e i fallimenti dei trasporti sono visibili in `status.reliability`.

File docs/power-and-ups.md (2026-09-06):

# Batteria e alimentazione

## Collegamento previsto

La Waveshare ESP32-S3-Touch-LCD-2.8 integra circuito di carica e gestione della
batteria. Il collegamento standard è:

```text
Alimentatore USB-C ------> USB-C Waveshare
LiPo 803040 3,7 V / 1000 mAh --> connettore BAT JST 1,25 mm Waveshare
3V3 + GND Waveshare ----> multiplexer e quattro AS5600
```

La batteria acquistata è una LiPo 803040 protetta da 1000 mAh, dimensioni
8 x 30 x 40 mm ([Amazon.it · B0G5NM9YJ4](https://www.amazon.it/dp/B0G5NM9YJ4)).
Verificare la polarità del connettore della batteria con serigrafia e
multimetro: lo stesso formato meccanico non garantisce la stessa disposizione
dei fili. Non collegare una LiPo a 3V3 o 5V e non mettere in parallelo il vecchio
caricatore/boost bq25185 con quello integrato senza isolamento progettato.

## Monitoraggio implementato

Il firmware campiona GPIO8 più volte, usa la mediana per ridurre il rumore e
applica il rapporto del partitore previsto dalla scheda. Espone nel display,
nel portale, nello stato JSON e nei log:

- tensione della batteria;
- percentuale stimata;
- stato alimentazione esterna, se il rilevamento opzionale è abilitato;
- temperatura e accelerazione QMI8658;
- stato e data/ora RTC PCF85063;
- salute microSD, heap e Wi-Fi.

La percentuale è una stima basata sulla tensione, non una misura coulombmetrica;
varia con carico, temperatura e chimica della cella. La scheda non misura la
corrente in ampere, quindi autonomia e consumi reali richiedono uno strumento
esterno o un sensore dedicato.

## Rilevazione opzionale della rete

GPIO15 è riservato come ingresso digitale opzionale per distinguere USB/rete da
batteria. Non collegare mai direttamente 5 V al GPIO. Abilitare la funzione nel
portale solo dopo avere aggiunto un segnale protetto a 3,3 V e verificato con il
multimetro livelli e polarità. Senza questo collegamento il portale indica la
funzione come non configurata; la lettura della batteria su GPIO8 resta attiva.

## Prove obbligatorie

Prima dell'uso continuo verificare avvio a sola batteria, carica con sistema
acceso, temperatura, picchi Wi-Fi/microSD/speaker, spegnimento del display,
riaccensione, perdita e ritorno USB. La checklist completa è in
[`friday-hardware-validation.md`](friday-hardware-validation.md).

Riferimento: [documentazione ufficiale Waveshare](https://docs.waveshare.com/ESP32-S3-Touch-LCD-2.8).

## Firmware 2.1

Percentuale da curva LiPo approssimata, avviso basso livello con isteresi, luminosità e attenuazione configurabili. Tenendo premuto il tasto batteria per 2 secondi il firmware può chiudere la microSD e rilasciare POWER_HOLD; PWR è dedicato esclusivamente allo spegnimento. Il ripristino di fabbrica si avvia soltanto tenendo premuto BOOT per 10 secondi. Con USB presente può non spegnere fisicamente la scheda. Provare la sequenza sul dispositivo; resta una stima da tensione, senza misuratore di corrente.

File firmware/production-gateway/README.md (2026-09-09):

# Firmware operativo CaskLogic PesaLink

Firmware completo per la Waveshare ESP32-S3-Touch-LCD-2.8. Legge quattro AS5600
attraverso il PCA9546/TCA9546A, converte le posizioni in peso, registra gli
eventi sulla microSD e rende disponibile un pannello di amministrazione web.

Il dispositivo digitalizza la pesa meccanica esclusivamente per uso interno e
non fiscale. Le letture non sostituiscono uno strumento di pesatura omologato e
non sono valide per transazioni commerciali o verifiche metrologiche legali.

## Funzioni implementate

- scansione continua dei quattro sensori a 100 kHz;
- calibrazione persistente delle dieci posizioni di ogni manopola;
- distanza angolare circolare, tolleranza, isteresi e finestra di stabilità;
- display ST7789 240×320 controllabile dal web, con luminosità, attenuazione e spegnimento automatico indipendenti, cinque pagine a card, swipe orizzontale, scroll verticale, footer touch e fallback BOOT;
- touch con autodetect CST3530 per V2 e CST328 per V1;
- doppio tono su speaker PCM5101 alla conferma della pesata, disabilitabile e persistente dal portale;
- volume speaker persistente da 0 a 100%, applicato sia alla conferma sia alla prova audio manuale;
- palette copiata dal portale interno del dispositivo e rendering incrementale per eliminare i lampeggiamenti degli aggiornamenti live;
- monitoraggio integrato di batteria GPIO8, QMI8658 e RTC PCF85063;
- storico e log NDJSON settimanali in cartelle anno/mese su microSD FAT32;
- campione diagnostico dei quattro sensori registrato ogni minuto;
- sincronizzazione NTP richiesta subito dopo il Wi-Fi e completata senza
  bloccare l'avvio o la lettura dei sensori;
- Wi-Fi DHCP o statico, scansione reti e access point captive di recupero che resta disponibile durante il provisioning;
- autenticazione HTTP Basic, rate limit, CSRF e header browser restrittivi;
- invio asincrono HTTPS e MQTT TLS opzionale verso il futuro backend CaskLogic;
- firma HMAC-SHA256 delle pesate, endpoint Prometheus e configurazione remota
  versionata con whitelist e copia locale valida;
- nessuna coda persistente di trasmissione: la microSD conserva lo storico, ma
  gli eventi MQTT non consegnati non vengono accodati per un reinvio;
- CA obbligatoria, soli endpoint HTTPS e certificato client mTLS opzionale;
- heartbeat con watchdog opzionale e protezione persistente dai reboot loop;
- storico filtrabile e ordinabile, con sole 20 righe al primo caricamento ed
  export coerente con i filtri;
- rotazione dimensionale e retention delle pesate configurabili;
- tensione e stima percentuale della batteria integrata su GPIO8;
- rilevazione opzionale della perdita di alimentazione esterna;
- autodiagnosi, grafici delle ultime 24 ore e pacchetto assistenza ZIP
  anonimizzato;
- controllo periodico della microSD e contatori di errore/magnete per sensore;
- aggiornamento firmware OTA a blocchi, firmato ECDSA-P256, con avanzamento,
  doppia partizione, rollback e registro degli aggiornamenti;
- simulatore locale che usa gli stessi file HTML, CSS e JavaScript incorporati.

## Compilazione

Il progetto usa Arduino ESP32 3.x tramite la piattaforma pioarduino. Il profilo
predefinito è la revisione Waveshare V2 con touch CST3530; il secondo profilo
mantiene la compatibilità con la V1 dotata di CST328. Su Windows conviene usare
una cache PlatformIO corta per evitare il limite storico dei percorsi:

```powershell
py -m pip install --user platformio
$env:PLATFORMIO_CORE_DIR = 'C:\pio'
py -m platformio run -e waveshare_esp32s3_touch_lcd_28_v2
py -m platformio run -e waveshare_esp32s3_touch_lcd_28_v1
```

Artefatti principali:

- `.pio/build/<profilo>/firmware.signed.bin`: aggiornamento OTA accettato dal
  portale;
- `.pio/build/<profilo>/firmware.bin`: binario non firmato usato come input
  della firma, non caricabile dal portale;
- `.pio/build/<profilo>/firmware.factory.bin`: prima installazione completa,
  da usare quando si passa dalla vecchia ESP32-C6 alla ESP32-S3.

Misure della build `2.1.3` verificata il 6 settembre 2026 sui profili Waveshare V2/V1:

- RAM statica: `59.036 / 327.680 byte` (`18,0%`);
- flash applicazione: `1.718.662 / 6.291.456 byte` (`27,3%`).

Le due partizioni OTA occupano `0x600000` byte, cioè 6 MiB ciascuna, sulla flash
da 16 MB. La partizione SPIFFS è stata rimossa perché gli asset web sono
incorporati nel firmware e i dati operativi risiedono sulla microSD.

La RAM allocata dinamicamente per coda HTTPS, task e richieste web non è
compresa nel primo valore; prima dell'installazione operativa va quindi
controllato anche l'heap libero esposto nella pagina Sistema.

Il file `include/WebAssets.h` è generato automaticamente da `data/` prima della
compilazione. Deve essere versionato affinché il contenuto web incorporato resti
ispezionabile e riproducibile.

La procedura di gestione delle chiavi e descritta in
[`../../docs/firmware-signing.md`](../../docs/firmware-signing.md). La chiave
privata non appartiene al repository e deve essere custodita e sottoposta a
backup separatamente.

## Simulatore e test API

```powershell
npm test
npm run simulate
```

Il simulatore risponde su `http://127.0.0.1:4177` e consente di provare tutte le
sezioni dell'interfaccia senza la scheda collegata.

## Prima configurazione

Se non trova credenziali Wi-Fi salvate, il dispositivo crea:

- SSID `LP-PW_casklogic-192_168_4_1`;
- password `casklogic`;
- indirizzo `http://192.168.4.1`.

Lo stesso access point viene attivato se la rete configurata non è raggiungibile.
Il salvataggio delle credenziali non riavvia il dispositivo durante il provisioning:
la connessione alla rete scelta viene provata mantenendo disponibile il portale.
Il dispositivo continua a tentare la riconnessione e spegne automaticamente
l'access point soltanto dopo 120 secondi consecutivi di connessione stabile alla rete
principale. Le sonde captive di iOS, Android e Windows vengono ricondotte al portale,
così il telefono non deve interpretare l'AP come una rete da abbandonare. Durante il primo provisioning l'interfaccia è raggiungibile dalla
rete creata dal dispositivo e richiede già l'utente `admin` e la password
iniziale `casklogic`. Le stesse credenziali proteggono il portale
dopo il salvataggio del Wi-Fi. La password non viene stampata sulla seriale e
va cambiata dalla sezione Sistema prima dell'uso operativo.

## File sulla microSD

La scheda deve essere FAT32. Il firmware crea:

```text
/weights/YYYY/MM/history-YYYY-Www.ndjson
/logs/YYYY/MM/system-YYYY-Www.ndjson
/weights/unsynced/history-<boot-id>.ndjson
/logs/unsynced/system-<boot-id>.ndjson
/updates/registry.ndjson
```

Lo storico viene scritto soltanto quando tutte le cifre sono valide, la misura
rimane stabile per la finestra configurata e il peso stabile cambia. I file
vengono ruotati con nomi univoci e gli archivi non vengono sovrascritti. La
pagina Storico legge soltanto le 20 righe più recenti all'apertura e applica
filtri e ordinamento lato dispositivo; l'export usa gli stessi filtri attivi.
L'esito di pubblicazione più recente è visibile nello stato integrazione, mentre
il record locale rimane immutabile e non costituisce conferma di ricezione.
La pagina Sistema offre separatamente l'export completo dei log, inclusi i
campioni periodici di presenza, angolo, stato magnete, AGC e magnitudine.

Le regole di esposizione in rete, il limite dell'HTTP locale e la cifratura
verso CaskLogic sono descritte in [`../../docs/security.md`](../../docs/security.md).

## Collaudo hardware completato

Display, touch, speaker, batteria, RTC, IMU, SD_MMC, bus I2C esterno, quattro
AS5600, calibrazione e integrazione CaskLogic sono stati collaudati sul sistema
installato. La prima installazione richiede comunque il file factory tramite
USB: un OTA della precedente ESP32-C6 non può trasformare o migrare l'hardware.

Gli esiti e la sequenza eseguita sono in
[`../../docs/friday-hardware-validation.md`](../../docs/friday-hardware-validation.md).

## Versione 2.2.7

I grafici diagnostici sono ordinati cronologicamente. La pagina Sistema mostra
uptime, istante di avvio, temperatura interna della CPU, temperatura del QMI8658
e frequenza CPU corrente. La CPU resta fissa a 240 MHz: selettore e profili ridotti
sono stati rimossi. I log completi vengono trasferiti da un task a bassa priorità
in blocchi da 2 KB, mentre lo storico ordinario mostra cinque pesate. Il riavvio
può essere disattivato oppure programmato ogni giorno o ogni settimana. Le nuove
preferenze sono memorizzate separatamente dalle calibrazioni. La rilevazione della
chiusura è documentata come collaudata e resta configurabile.

SSH/SFTP non è incluso: l'esempio ESP32 disponibile implementa un ponte SSH verso
UART, mentre l'accesso SFTP alla microSD richiede un secondo stack crittografico e
un adattamento specifico del filesystem. Su questo dispositivo avrebbe un impatto
non accettabile sulla priorità riservata ad acquisizione e invio.

## Versione 2.1.3

Il conto alla rovescia del ripristino forza la riattivazione del pannello anche
quando il display è spento. Il ripristino è disponibile esclusivamente tenendo
premuto BOOT per 10 secondi. Il tasto alimentazione PWR è dedicato soltanto allo
spegnimento e non può cancellare la configurazione.

## Versione 2.1.1

Acquisizione dedicata a 50 Hz, trasporti prioritari indipendenti, RTC UTC offline,
calibrazioni versionate con CRC, riordino dei canali, diagnosi del rumore,
conferme distinte di salvataggio/consegna, rilevazione della chiusura bascula,
provisioning Wi-Fi stabile e spegnimento automatico del display.
La rilevazione è inizialmente disattivata. Parametri e prove:
[guida 2.1](../../docs/reliability-2.1.md).

Per i test C++ del nucleo, con un compilatore host:

```sh
g++ -std=c++17 -Wall -Wextra -Werror -Iinclude src/ScaleCore.cpp src/ReliabilityCore.cpp tests/reliability_test.cpp -o reliability-test
./reliability-test
```

Per aggiornare una scheda già configurata usare OTA firmato o l'upload PlatformIO
con file separati. Il binario factory combinato può cancellare la NVS: riservarlo
alla prima installazione. Il comando seriale `status` restituisce lo stato corrente.

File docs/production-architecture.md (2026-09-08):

# Architettura operativa CaskLogic PesaLink

Il sistema CaskLogic PesaLink descritto qui è implementato in
`firmware/production-gateway`. Il backend e il kiosk CaskLogic restano separati
e non sono modificati da questo progetto.

## Responsabilità

```text
AS5600 x4
   │ angoli grezzi
   ▼
ESP32 ── calibrazione, isteresi, stabilità ── snapshot peso valido
   │
   │ connessione persistente autenticata
   ▼
Backend ── stato della sessione di pesatura ── Kiosk
                                                │
                                                ├─ Lordo
                                                ├─ Tara
                                                └─ Inserimento manuale
```

### ESP32

L'ESP32 legge continuamente i quattro sensori anche quando non deve trasmettere.
Pubblica un evento soltanto quando cambia lo snapshot stabile o quando scade un
heartbeat. Non decide lordo/tara e non conferma una pesata.

### Backend

Il backend mantiene l'ultima misura live, verifica autenticità, sequenza,
validità e freschezza. Deve separare la semplice anteprima live dalla conferma
persistente della pesata.

### Kiosk

Il kiosk sceglie la destinazione in base al flusso operativo:

- nuova pesata o nuovo fornitore: anteprima nel `Lordo`;
- riapertura di una bozza che possiede già il lordo: anteprima nella `Tara`;
- dalla selezione utenti, l'avvio di una pesata automatica può aprire
  l'operatore configurato e predisporre il lordo;
- il richiamo di una bozza non deve mai sovrascrivere il lordo esistente.

Il peso diventa definitivo soltanto con una conferma esplicita dell'operatore.

## Inserimento manuale

La modalità manuale deve essere sempre disponibile. Quando l'operatore modifica
un campo manualmente, il flusso automatico non deve sovrascriverlo. Una possibile
macchina a stati è:

```text
AUTO_IN_ATTESA
  ├─ movimento manopola ──> AUTO_LIVE
  └─ focus/tastierino ─────> MANUALE

AUTO_LIVE
  ├─ conferma pesata ──────> AUTO_IN_ATTESA (pesata successiva)
  └─ pulsante manuale ─────> MANUALE

MANUALE
  ├─ input operatore ──────> resta MANUALE
  └─ movimento manopola con consenso ──> AUTO_LIVE
```

Dopo la conferma della pesata successiva, l'interfaccia torna predisposta per
l'inserimento manuale finché una manopola non viene realmente movimentata.

## Snapshot implementato

Il contratto è versionato e ogni evento contiene uno snapshot completo:

```json
{
  "type": "scale.snapshot",
  "schema_version": 1,
  "device_id": "pesalink-01",
  "boot_id": "uuid-generato-al-riavvio",
  "sequence": 1842,
  "captured_ms": 983442,
  "digits": [1, 2, 3, 4],
  "multipliers_kg": [10000, 1000, 100, 10],
  "fixed_units_kg": 0,
  "weight_kg": 12340,
  "stable": true,
  "valid": true,
  "sensor_flags": ["OK", "OK", "OK", "OK"]
}
```

I moltiplicatori e l'ordine delle manopole vanno confermati durante la
calibrazione reale.

## Trasporto

Il dispositivo usa richieste `HTTPS POST` asincrone e può pubblicare via MQTT
TLS senza interrompere la scansione dei sensori. Il certificato CA deve essere
configurato dall'interfaccia web; il firmware rifiuta endpoint HTTP e TLS privo
di una CA attendibile. Certificato e chiave client opzionali consentono mTLS.
Ogni pesata può essere firmata HMAC-SHA256. Non è presente una coda persistente
di trasmissione. Il backend deve includere:

- TLS con CA configurata sul dispositivo;
- autenticazione per dispositivo;
- verifica HMAC in tempo costante e deduplicazione per `event_id`;
- heartbeat e timeout di misura scaduta;
- riconnessione con backoff;
- `boot_id` e `sequence` per deduplicazione e riordino;
- snapshot completo a ogni evento, non la sola cifra modificata;
- nessuna persistenza automatica del lordo/tara senza conferma dell'operatore.

Il portale locale resta HTTP ed e destinato a una VLAN tecnica amministrata
dall'access point, con ACL che ne limitino l'accesso. Autenticazione Basic,
rate limit, CSRF e header restrittivi riducono il rischio applicativo ma non
sostituiscono la cifratura del trasporto. Dettagli in
[`security.md`](security.md).

## Affidabilità

- watchdog hardware alimentato soltanto da task realmente sani;
- riconnessione Wi-Fi e backend indipendenti dalla scansione locale;
- configurazione Wi-Fi e backend non inclusa in chiaro nel repository;
- sincronizzazione remota solo di campi operativi in whitelist, con versione
  crescente e conservazione dell'ultima copia locale valida;
- watchdog heartbeat opzionale con un solo riavvio e inibizione persistente
  fino alla successiva risposta valida;
- stato locale evidente: sensori, Wi-Fi, backend e misura valida;
- calibrazione salvata con versione e checksum;
- fallback manuale completo quando sensori o rete non sono disponibili.

## Aggiornamento 2.1

Il percorso di acquisizione e i trasporti pesate sono ora task distinti dalle funzioni accessorie. La calibrazione è versionata e protetta da CRC. Consultare [la guida 2.1](reliability-2.1.md) per code, stabilità dopo pause, RTC, ordine sensori e completamento della pesata.

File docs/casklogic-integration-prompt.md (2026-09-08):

# Prompt per integrare CaskLogic

Usare questo prompt in un'attività separata aperta sul repository CaskLogic:

```text
Nel repository C:\GESTIONALE-TESTA-E-CODA\CaskLogic-GestionaleSfuso implementa
l'integrazione del sistema CaskLogic PesaLink collegato alla pesa Laveggio
Printomatic. Prima leggi, senza
modificarlo, il contratto nel repository
C:\GESTIONALE-TESTA-E-CODA\Laveggio-Printomatic\docs\casklogic-integration-contract.md
e verifica i pattern già presenti nel backend, nel realtime e nel kiosk.

Implementa POST /api/v1/scale-devices/events con autenticazione Bearer per
dispositivo, token conservati solo come hash, validazione schema version 1 e
deduplicazione atomica per event_id e per device_id, boot_id e sequence.
Verifica la firma HMAC-SHA256 con confronto in tempo costante usando un segreto
distinto per dispositivo e il formato canonico documentato nel contratto.
Separa rigorosamente
l'ultima misura live e la sua scadenza dalle pesate confermate e canoniche. Gli
eventi scale.snapshot e scale.heartbeat devono aggiornare il kiosk attraverso
il canale realtime esistente; device.power deve alimentare audit e notifiche
configurabili lato backend. Non usare la microSD del dispositivo come fonte
canonica, non implementare accesso NAS e non introdurre una coda persistente
sul dispositivo.

Integra MQTT tramite TLS come canale realtime opzionale e preferenziale, senza
eliminare l'endpoint HTTPS di compatibilità. Implementa ACL per dispositivo sui
topic availability, weights, status, commands e command-acks descritti nel
contratto, Last Will offline, stato online/freschezza e test di riconnessione.
I soli comandi ammessi al gateway sono display.set, config.sync e
diagnostics.run; genera command_id univoci e registra richiesta ed esito.

Esponi l'endpoint esclusivamente in HTTPS. Prevedi mTLS opzionale al reverse
proxy/backend, con associazione del certificato client al device_id e
rotazione/revoca amministrabile. L'heartbeat deve ricevere rapidamente una
risposta 2xx, aggiornare ultimo contatto e audit del dispositivo e non deve
attivare elaborazioni che possano far scattare impropriamente il watchdog del
gateway. Aggiungi test per CA/certificato client non valido, token revocato,
firma HMAC errata, duplicati, ACL MQTT, heartbeat e timeout.

Implementa l'endpoint GET HTTPS di configurazione remota versionata. Restituisci
304 quando la versione del dispositivo e corrente, oppure una versione
strettamente crescente contenente solo i campi in whitelist indicati nel
contratto. Non inviare mai Wi-Fi, credenziali amministrative, token o chiavi
TLS. Aggiungi monitoraggio centralizzato interrogando GET /api/metrics con il
token dedicato e mostra uptime, heap, rete, microSD, batteria, MQTT e contatori
sensori. Non esporre il portale ESP32 a Internet: l'accesso deve restare nella
VLAN tecnica con ACL.

Nel kiosk mantieni sempre disponibile l'inserimento manuale. Un aggiornamento
automatico non deve sovrascrivere un campo mentre l'operatore lo sta editando e
non deve mai salvare automaticamente lordo, tara o una pesata. Per una nuova
pesata mostra il valore live come proposta di Lordo; per una bozza che possiede
già il lordo proponilo come Tara senza toccare il lordo esistente. La conferma
dell'operatore resta obbligatoria. Mostra stato dispositivo, freschezza,
stabilità e fallback manuale quando il dato è assente o scaduto.

Aggiungi migrazioni, modelli, servizi, endpoint amministrativi per registrare e
revocare dispositivi, audit filtrabile, test backend, test frontend e verifica
browser autenticata. Riusa grafica, dialoghi e convenzioni già presenti nel
gestionale. Non modificare flussi estranei e non eseguire deploy, commit o push
finché non te lo autorizzo esplicitamente. Alla fine elenca file modificati,
test eseguiti e risultati del collaudo hardware completato.
```

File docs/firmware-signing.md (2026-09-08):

# Firma e rilascio firmware

Il portale OTA, dalla versione 1.2.0, accetta soltanto immagini
`firmware.signed.bin` firmate ECDSA-P256 con SHA-256. La chiave pubblica è
incorporata in `include/OtaPublicKey.h`; la chiave privata non deve mai entrare
nel repository, nel dispositivo o nel pacchetto assistenza.

## Chiave di firma

Il build script cerca per impostazione predefinita:

```text
%USERPROFILE%\.casklogic\pesalink-signing\private_key.pem
~/.casklogic/pesalink-signing/private_key.pem
```

La posizione può essere sostituita con `PESALINK_SIGNING_KEY`. Per continuità
con le installazioni precedenti, il processo accetta anche il percorso storico
`.casklogic\laveggio-signing\private_key.pem` e la variabile
`LAVEGGIO_SIGNING_KEY`. La chiave va
conservata in un archivio cifrato, con backup offline e accesso limitato agli
operatori autorizzati. La perdita della chiave impedisce nuovi aggiornamenti
OTA ai dispositivi che incorporano la relativa chiave pubblica; una sua
compromissione richiede una procedura fisica controllata di rotazione.

La chiave di produzione corrente è stata ruotata il 6 settembre 2026. Impronta
SHA-256 della chiave pubblica in formato SubjectPublicKeyInfo DER:

```text
9e92fbe706ddb18feddb24c1fddf581cced623ce5340a6c053ff1dc96aaf41e1
```

Su macOS o Linux una nuova coppia può essere creata così. Questi comandi non
devono essere ripetuti se la chiave esiste già:

```sh
install -d -m 700 ~/.casklogic/pesalink-signing
openssl genpkey -algorithm EC -pkeyopt ec_paramgen_curve:P-256 \
  -out ~/.casklogic/pesalink-signing/private_key.pem
openssl pkey -in ~/.casklogic/pesalink-signing/private_key.pem -pubout \
  -out ~/.casklogic/pesalink-signing/public_key.pem
chmod 600 ~/.casklogic/pesalink-signing/private_key.pem
```

Una rotazione richiede poi di rigenerare `OtaPublicKey.h` e installare via USB
il nuovo firmware su ogni dispositivo: il vecchio firmware non può accettare
un OTA firmato dalla nuova chiave.

Per rigenerare l'header pubblico da un PEM pubblico:

```powershell
py tools/public_key_to_header.py `
  C:\percorso\public_key.pem `
  include/OtaPublicKey.h
```

Su macOS o Linux:

```sh
python3 tools/public_key_to_header.py \
  ~/.casklogic/pesalink-signing/public_key.pem include/OtaPublicKey.h
```

## Build e verifica

`platformio.ini` esegue automaticamente `tools/sign_firmware.py` dopo la
compilazione. Il file caricato dal portale deve essere quello firmato:

```powershell
$env:PLATFORMIO_CORE_DIR = 'C:\pio'
py -m platformio run
```

Lo script rifiuta chiavi private con permessi troppo aperti e verifica che la
loro impronta corrisponda alla chiave pubblica incorporata, evitando di creare
un artefatto che i dispositivi rifiuterebbero.

La firma DER è aggiunta al binario in un blocco finale da 512 byte, come
richiesto da `Update.installSignature()`. Il firmware verifica firma e
dimensione prima di selezionare la nuova partizione. Al primo avvio esegue i
controlli minimi e marca l'immagine valida; in caso contrario richiede il
rollback. Ogni tentativo viene registrato in `/updates/registry.ndjson`.

Dal portale, la selezione del file è l'unica operazione manuale. Il browser
trasmette blocchi ordinati da 12 KiB, verificati per offset e completezza, così
anche una rete debole non dipende da una singola richiesta HTTP molto lunga.
Dopo la conferma vengono mostrati avanzamento, verifica della firma, riavvio
automatico e versione effettivamente tornata online. Un errore resta visibile
nel pannello senza essere affidato soltanto a una notifica temporanea.

Questa protezione impedisce l'installazione dal portale di un binario non
firmato. Non protegge da un attaccante con accesso fisico alla flash finché non
vengono provisionati anche Secure Boot e Flash Encryption tramite eFuse. Tali
operazioni sono irreversibili e vanno eseguite sulla scheda installata seguendo
la procedura di recupero già documentata.

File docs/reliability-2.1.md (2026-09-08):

# Affidabilità e chiusura della bascula — 2.1.0

## Priorità operative

L'acquisizione dei quattro AS5600 usa un task dedicato sul core 1, priorità 5,
con periodo nominale di 20 ms. Il task possiede il bus I2C esterno; portale,
display, microSD, NVS, DNS e sincronizzazione remota non eseguono operazioni
all'interno del percorso di acquisizione.

Gli snapshot stabili entrano in una coda RAM senza attese, prima della
telemetria opzionale della scheda. Un dispatcher sul core 0, priorità 4,
prepara i messaggi e alimenta due trasporti indipendenti, HTTPS e MQTT,
priorità 3. Heartbeat e servizi accessori non condividono la coda delle pesate.
Lo storico viene elaborato separatamente dal ciclo del portale.

Le code sono limitate: 32 snapshot in acquisizione, 32 per trasporto e 64
record di archivio. Le code grandi usano PSRAM. Eventuali saturazioni sono
contate ed esposte, senza bloccare il campionamento. Non sono una coda
persistente, non sopravvivono al riavvio e non reinviano automaticamente lo
storico. Un guasto di rete o del destinatario può ancora impedire la consegna.

L'IMU viene interrogata dopo le letture, solo nel tempo residuo disponibile.
RTC e batteria vengono aggiornati circa ogni secondo. Non si presume che un
microcontrollore general purpose garantisca assenza assoluta di jitter:
scritture flash/NVS, OTA, guasti elettrici e timeout I2C richiedono misure sul
dispositivo. Intervallo massimo, ritardi, età del campione e saturazioni sono
visibili in Sistema e in `GET /api/status`, sezione `reliability`.

Una pausa superiore a 100 ms azzera la stabilizzazione: due letture uguali
separate da un intervallo non osservato non confermano un peso. Stato del
magnete e angolo vengono letti insieme a ogni scansione.

## Ora senza rete

Il PCF85063 conserva UTC. All'avvio si controllano BCD, calendario, anno,
indicatore di arresto dell'oscillatore e bit STOP, prima di impostare l'ora di
sistema. Il fuso POSIX riguarda solo la presentazione e le cartelle locali.

Per migrare dai firmware che scrivevano l'ora locale serve una prima
sincronizzazione NTP riuscita: il firmware marca il formato UTC soltanto dopo
la scrittura e lettura valide del RTC. Un RTC vecchio di formato ignoto non
viene interpretato arbitrariamente come UTC. È necessaria alimentazione di
backup del RTC per conservarlo dopo lo spegnimento completo.

`time_source` distingue `ntp`, `rtc` e `unavailable`; `time_synchronized`
indica una sincronizzazione NTP in questo avvio, mentre `time_valid` indica
che lo snapshot possiede un timestamp. Gli eventi conservano l'istante di
acquisizione anche se archivio o invio avvengono successivamente.

## Stabilità, archivio e consegna

- **Stabile**: le cifre valide sono rimaste invariate per la finestra impostata.
- **Salvata su microSD**: apertura e scrittura della riga sono riuscite; il file
  viene scaricato e chiuso. Un errore non produce il tono di successo.
- **Ricevuta dal gestionale**: risposta HTTPS 2xx allo specifico evento.
- **Pubblicata MQTT**: scrittura sul trasporto MQTT QoS 0 riuscita; non è una
  conferma applicativa del gestionale.

Il display e il portale mostrano lo stato dell'ultimo snapshot. Gli esiti di
trasporto sono anche righe `delivery.result` nei log, correlate per `event_id`.
Lo storico originale mantiene `delivery=requested` quando l'invio è richiesto:
quel valore, da solo, non è una ricevuta. La conferma operatore della pesata
nel gestionale rimane un'azione distinta.

## Calibrazione e ordine sensori

In Calibrazione, **Ordine delle cifre** associa le quattro posizioni logiche ai
canali fisici 0–3 del multiplexer. Ogni canale deve comparire esattamente una
volta. I 10 punti, il rumore e i riferimenti magnetici restano associati al
sensore fisico; i moltiplicatori appartengono alle posizioni logiche.

Esempio: con ordine `[3,1,2,0]`, la prima cifra proviene dal canale fisico 3 e
usa il primo moltiplicatore. Non occorre spostare cavi o ricatturare i punti.
Dopo ogni cambio ordine verificare il peso ricostruito sulla meccanica installata.

Una cattura richiede 25 campioni sani, un campione recente e dispersione non
superiore a 12 unità raw. Punti con distanza circolare minore o uguale a
`2 × tolleranza + isteresi` sono rifiutati perché le regioni si sovrappongono.
La pagina mostra rumore, margine rispetto alla tolleranza e scostamento della
magnitudine rispetto al punto memorizzato. Questi dati aiutano a riconoscere
movimenti del supporto o del magnete; non stimano autonomamente un errore in kg.

Calibrazioni e ordine vengono salvati insieme in un blob NVS con schema,
revisione e CRC32, conservando la lettura del formato precedente per la
migrazione. Un blob danneggiato disabilita i punti: nessuna misura valida viene
ricostruita usando una calibrazione non verificata. Gli snapshot riportano
`calibration_revision` e `sensor_order`.

## Chiusura della bascula

La funzione è collaudata e disattivata per impostazione iniziale. Si configura in
**Sistema → Chiusura della bascula**.

| Parametro | Valore iniziale | Significato |
| --- | ---: | --- |
| Abilita rilevazione | No | Attiva acquisizione IMU più frequente e rilevatore |
| Segnala peso completato | No | Se disattivato, sola osservazione locale |
| Soglia colpo | 0,35 g | Accelerazione rispetto alla componente lenta/gravitazionale |
| Soglia quiete | 0,08 g | Livello massimo dopo il colpo |
| Quiete minima | 400 ms | Durata continuativa richiesta sotto la soglia |
| Tempo massimo | 3000 ms | Scadenza del candidato dopo il colpo |
| Pausa fra rilevazioni | 2000 ms | Evita conteggi ripetuti della stessa chiusura |

Il rilevatore usa il modulo tridimensionale dell'accelerazione dopo un filtro
passa-alto: impulso, quiete, lettura valida e stabile. Un intervallo IMU non
osservato superiore a 100 ms annulla il candidato. Il campionamento nominale
è 50 Hz: impulsi molto brevi possono sfuggire. Vibrazione corrente, picco,
candidati e numero di rilevazioni sono visibili dal portale.

In **sola osservazione** viene creato un evento locale `scale.closure_candidate`
nei log, senza inviare colpi al destinatario delle pesate. Con **Segnala peso
completato** viene generato uno `scale.snapshot` aggiuntivo con
`closure_detected=true`, `weight_completed=true` e
`completion_experimental=true`. Il flusso ordinario degli snapshot stabili
continua sempre. Un peso uguale al precedente può produrre un nuovo evento
di completamento dopo una nuova chiusura riconosciuta.

### Procedura di configurazione e verifica

1. Fissare la scheda al supporto definitivo: viene misurato il movimento della
   scheda, non quello di un componente remoto.
2. Abilitare solo la rilevazione; lasciare disattivato il completamento.
3. Registrare chiusure vere, movimenti delle manopole, urti sul banco e rumore
   normale; confrontare picchi, conteggi e mancate rilevazioni.
4. Regolare soglia del colpo, quiete, durata e pausa. Ripetere con chiusure
   leggere e forti; controllare falsi positivi e negativi.
5. Dopo il confronto meccanico attivare, se desiderato, il completamento.
   Il backend lo tratta come suggerimento, mai come conferma operatore.

## Display, audio e batteria

Luminosità 5–100%, attenuazione dopo inattività (0 disabilita) e spegnimento
completo opzionale dopo 1–1440 minuti. Il touch o BOOT riattivano il pannello
senza fermare acquisizione, rete o invii. Gli interruttori display e speaker restano indipendenti. La percentuale
batteria usa una curva approssimata LiPo: è ancora una stima da tensione, non
un misuratore di corrente o autonomia. L'avviso di batteria bassa è regolabile
e usa isteresi per evitare ripetizioni.

Il tasto batteria richiede prima un rilascio. Se lo spegnimento è abilitato,
tenendolo premuto per 2 secondi il firmware chiude la microSD, spegne il display
e rilascia POWER_HOLD. PWR non esegue mai il ripristino di fabbrica.
Il ripristino è disponibile esclusivamente tenendo premuto BOOT per 10 secondi;
il suo conto alla rovescia forza la riattivazione del pannello anche se era
spento manualmente o per inattività.
Con USB collegata la scheda può restare alimentata dopo lo spegnimento; letture
e invio continuano, mentre la SD resta chiusa fino al riavvio.

## API e manutenzione

- `GET/POST /api/settings/reliability`: impostazioni display, batteria e bascula.
- `POST /api/calibration/order`: `slot_0`…`slot_3`, permutazione dei canali 0–3.
- `GET /api/calibration`: ordine, revisione e punti fisici.
- `GET /api/status`: stato operativo, telemetria e ricevuta dell'ultimo evento.
- Comando seriale `status` seguito da invio, a 115200 baud: stato in sola lettura.
- Comando seriale `diagnostics`: autodiagnosi, inclusa prova di scrittura SD.
  Eseguirlo fuori dalla pesatura operativa per un collaudo controllato.

Le nuove impostazioni di affidabilità sono persistite in un unico record NVS;
un errore di salvataggio restituisce errore e conserva la configurazione attiva.

Le scritture HTTP mantengono autenticazione e protezione CSRF. La conferma
della chiusura ha una firma aggiuntiva `completion_signature`, oltre alla firma
storica del peso. Il formato di firma e la gestione degli eventi sono descritti
nel contratto d'integrazione. Il collaudo completato comprende il confronto
fisico con la bascula e il destinatario gestionale effettivo.

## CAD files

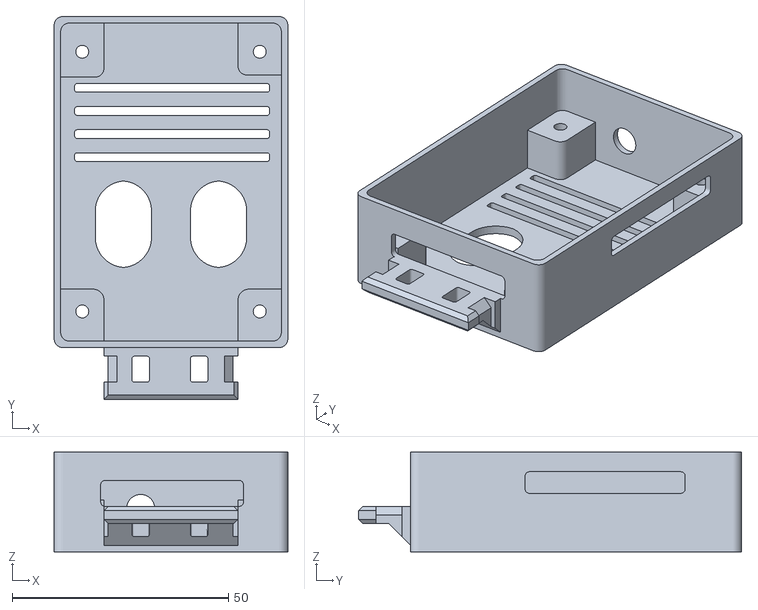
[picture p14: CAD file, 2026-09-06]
stl/original-designs/esp32-s3-touch-lcd-2_8-v01.stl
54.0 x 88.5 x 23.0

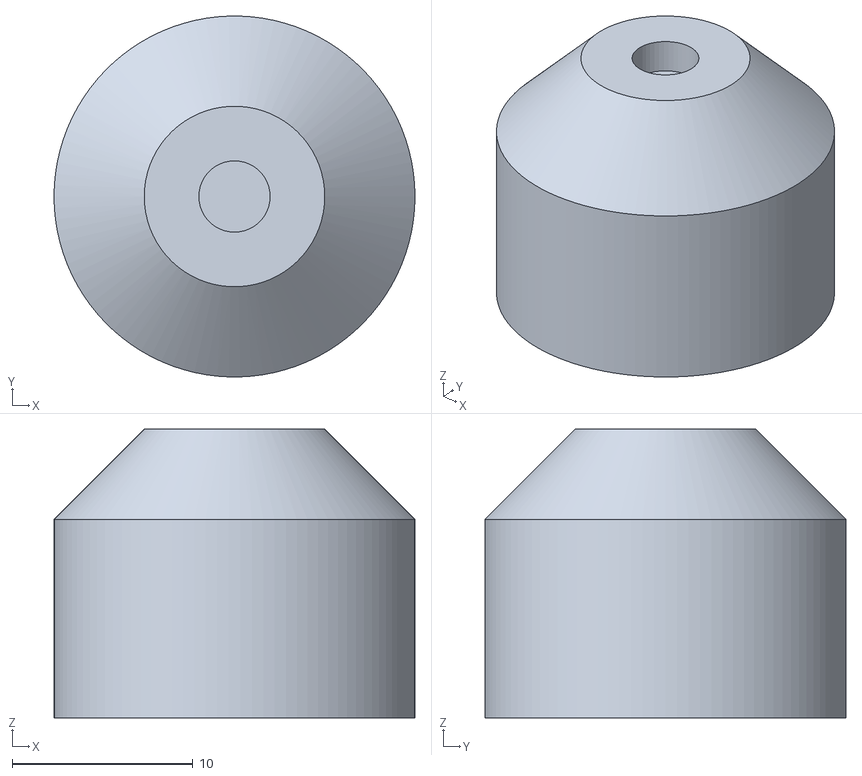
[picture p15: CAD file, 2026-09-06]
stl/original-designs/boccola-calamita-v4.stl
20.0 x 20.0 x 16.0

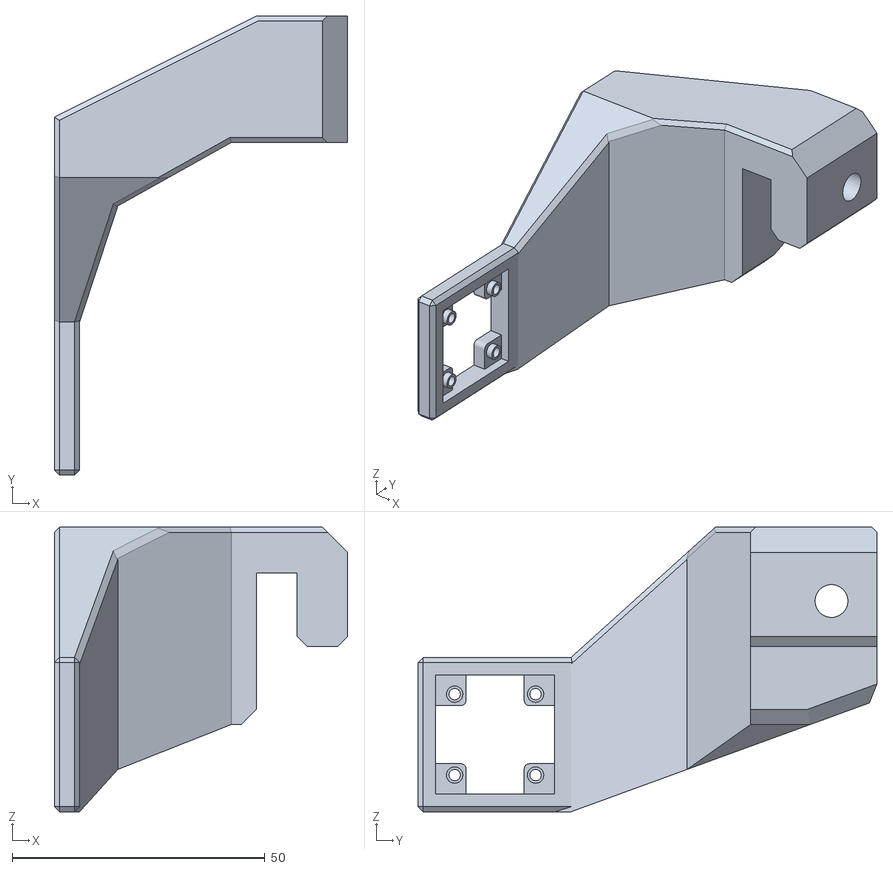
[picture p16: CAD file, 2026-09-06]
stl/original-designs/supporto-sensore.stl
58.0 x 90.8 x 56.2

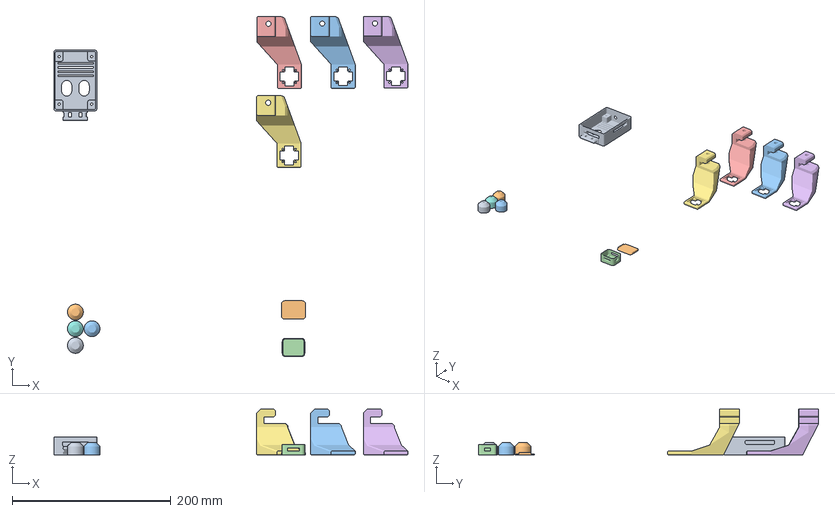
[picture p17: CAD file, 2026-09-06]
stl/original-designs/pesalink-v2.3mf
446.6 x 429.5 x 58.0 mm
esp32-s3-touch-lcd-2_8-V01.stl
3d Print Top for Adafruit 5664 PCA9546 v6.stl
Supporto sensore.stl x 4
3d Print for Adafruit 5664 PCA9546 Stemma QT v12.stl
Boccola calamita-v4.stl x 4

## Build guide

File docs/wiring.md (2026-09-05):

# Cablaggio

## Schema logico

```text
USB-C oppure LiPo 3,7 V
          |
          v
Waveshare ESP32-S3-Touch-LCD-2.8
  3V3  --------+------- VIN   PCA9546 Adafruit 5663
               +------- distribuzione VCC agli AS5600 #0-#3
  GND  --------+------- GND          |
               +------- distribuzione GND agli AS5600 #0-#3
  GPIO11 (SDA) -------- SDA          +-- SD0/SC0 -- AS5600 #0 SDA/SCL
  GPIO10 (SCL) -------- SCL          +-- SD1/SC1 -- AS5600 #1 SDA/SCL
                                      +-- SD2/SC2 -- AS5600 #2 SDA/SCL
                                      +-- SD3/SC3 -- AS5600 #3 SDA/SCL

Per ciascun canale: SDn -> SDA e SCn -> SCL. VCC e GND arrivano dalla
distribuzione comune e non vengono commutati dal multiplexer.
AS5600: DIR, GPO e OUT non collegati nella lettura I2C standard.
```

## Scheda verso multiplexer

| Waveshare ESP32-S3 | Multiplexer | Nota |
| --- | --- | --- |
| 3V3 | VIN | Alimentare allo stesso livello logico della Waveshare |
| GND | GND | Massa comune obbligatoria |
| GPIO11 | SDA | Bus esterno dedicato dal firmware |
| GPIO10 | SCL | Bus esterno dedicato dal firmware |
| GPIO18 | RST, opzionale | Collegare solo se si vuole il reset pilotato |

Il multiplexer funziona anche con il solo cablaggio a quattro fili se il suo
RST è già mantenuto alto dalla scheda. GPIO18 viene predisposto alto dal
firmware, ma non agisce se non è collegato fisicamente.

## Attenzione ai colori dei cavetti

Sul prototipo precedente alcuni connettori specchiavano l'ordine dei fili. Il
colore non identifica il segnale. Prima di alimentare:

1. scollegare USB-C e batteria;
2. leggere VIN, GND, SDA e SCL sulle serigrafie;
3. verificare ogni filo con il multimetro in continuità;
4. escludere corti tra VIN e GND;
5. collegare un solo AS5600 e verificare `0x70` e `0x36`;
6. aggiungere gli altri rami uno alla volta.

SDA/SCL invertiti impediscono la comunicazione; VCC/GND invertiti possono
danneggiare i componenti. Display, touch, audio, RTC, IMU e microSD sono già
cablati sulla Waveshare e non devono essere riportati sul bus esterno.

## Antenna Wi-Fi esterna

Il pigtail IPEX-1/U.FL verso SMA femmina si accoppia all'antenna 2,4 GHz con SMA
maschio. Il connettore IPEX1 della Waveshare non diventa attivo con il solo
inserimento del cavetto. Sul montaggio realizzato è stato necessario spostare
a sinistra la resistenza di selezione RF dalla posizione originale, usando un
saldatore ad aria calda e il flussante.

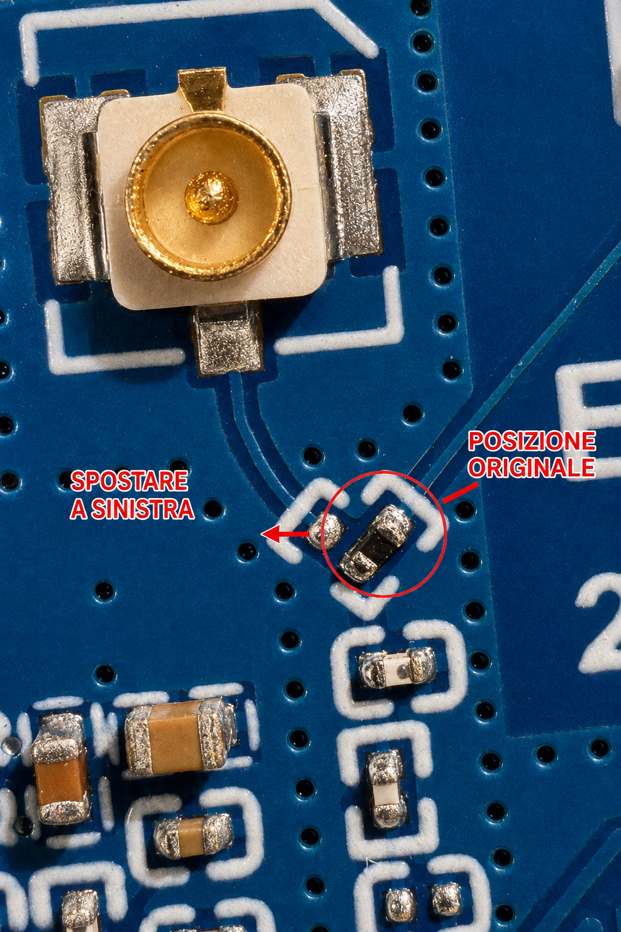
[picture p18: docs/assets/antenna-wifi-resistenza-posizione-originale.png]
Posizione originale della resistenza RF e direzione dello spostamento


La fotografia mostra la resistenza **prima** della modifica: va spostata sul
pad immediatamente a sinistra indicato dalla freccia. Eseguire l'intervento a
scheda disalimentata, proteggere il connettore IPEX1 dal calore, lasciare
raffreddare e verificare con lente o microscopio l'assenza di ponti di stagno
prima di ricollegare batteria e USB-C.

## Cavo dei sensori

Il Lapp LiYY 4 x 0,14 mm2 è un cavo a quattro conduttori non schermato. Usare un
conduttore per ciascuno dei segnali `3V3`, `GND`, `SDA` e `SCL`, mantenendo ogni
ramo quanto più corto possibile. I 10 m indicano la quantità acquistata, non la
lunghezza ammessa per una singola tratta I2C. Prima del montaggio definitivo
provare ogni spezzone a 100 kHz e ridurre frequenza o lunghezza se le letture non
sono affidabili.

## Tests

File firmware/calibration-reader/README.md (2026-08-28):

# Firmware 1 — lettura diagnostica e calibrazione

Questa cartella contiene il firmware attualmente disponibile e provato sulla
Waveshare ESP32-C6-LCD-1.47.

## Scopo

- individuare automaticamente il multiplexer agli indirizzi `0x70`–`0x77`;
- selezionare in sequenza i quattro canali;
- rilevare ciascun AS5600 all'indirizzo `0x36`;
- leggere il valore grezzo a 12 bit dai registri `0x0C`–`0x0D`;
- leggere periodicamente `STATUS`, `AGC` e `MAGNITUDE`;
- mostrare i quattro valori sul display senza refresh completo;
- produrre diagnostica JSON sulla seriale a `115200 baud`;
- rilevare una linea I2C bloccata bassa.

Questo sketch serve per montaggio, diagnosi e futura raccolta dei punti di
calibrazione. Non invia dati in rete e non calcola ancora le cifre meccaniche.

## Parametri attuali

| Parametro | Valore |
| --- | --- |
| SDA ESP32 | GPIO 1 |
| SCL ESP32 | GPIO 2 |
| Frequenza I2C | 100 kHz |
| Indirizzo multiplexer osservato | `0x70` |
| Indirizzo AS5600 | `0x36` |
| Intervallo nominale di lettura | 10 ms |
| Diagnostica magnetica | 250 ms |
| Seriale | 115200 baud |

## Interpretazione del display

- `S0`–`S3`: canale del multiplexer.
- `0000`–`4095`: angolo grezzo AS5600.
- `OK`: magnete rilevato con intensità nel campo accettabile.
- `MAG`: magnete assente, troppo debole o troppo forte.
- `----`: nessun AS5600 raggiungibile sul canale.

L'assenza del magnete rende l'angolo non utilizzabile anche se il chip continua
a rispondere via I2C.

## Calibrazione prevista

Per ciascuna manopola si dovranno registrare più campioni stabili per ogni
posizione meccanica:

- manopole `x10`, `x100`, `x1.000`: posizioni da 0 a 9;
- manopola `x10.000`: posizioni effettivamente disponibili sulla pesa;
- campioni presi possibilmente arrivando alla posizione da entrambe le
  direzioni, per misurare il gioco meccanico.

La futura tabella di calibrazione dovrà contenere centro angolare, tolleranza e
isteresi per ogni posizione, gestendo correttamente il passaggio circolare fra
`4095` e `0`.

## Limite attuale

La memorizzazione guidata delle posizioni non è ancora implementata. Per ora i
valori possono essere annotati osservando display e seriale.

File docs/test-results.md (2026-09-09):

# Risultati delle prove

## Firmware 2.2.7 — 9 settembre 2026

- `39/39` test API del simulatore superati, inclusi ordine cronologico dei
  campioni diagnostici, doppia temperatura, CPU fissa, riavvio programmato e conservazione delle calibrazioni.
- Build PlatformIO V2 riuscita e immagine OTA ECDSA-P256 firmata generata e
  verificata con la chiave pubblica incorporata.
- Portale verificato con gli asset incorporati: i grafici scorrono dal campione
  più vecchio a sinistra al più recente a destra; uptime, istante di avvio e
  temperature CPU e QMI8658 e frequenza CPU sono leggibili nella pagina Sistema.
- La frequenza CPU è fissata a 240 MHz. Se sulla 2.2.6 era stato salvato un
  profilo ridotto, la relativa chiave viene rimossa senza modificare le altre preferenze.
- L'export dei log usa un task separato a priorità bassa, snapshot delle dimensioni
  e blocchi da 2 KB; una seconda esportazione contemporanea viene rifiutata.
- Il caricamento ordinario dello storico restituisce cinque pesate e consulta al
  massimo gli ultimi 32 KB del file recente.
- Il collaudo sull'impianto installato è completato: quattro AS5600, calibrazione,
  display, touch, audio, microSD, RTC, batteria, Wi-Fi e integrazione CaskLogic
  sono stati verificati nel funzionamento operativo.
- L'aggiornamento OTA sostituisce soltanto la partizione applicativa; NVS,
  calibrazioni, configurazione di rete e dati su microSD restano invariati.
- Il riavvio programmato usa chiavi NVS indipendenti e non passa dal salvataggio
  del blocco `calibration_v1`.

## Firmware 2.1.3 — 6 settembre 2026

- Ripristino di fabbrica rimosso completamente dal tasto alimentazione: PWR
  gestisce soltanto lo spegnimento; BOOT resta l'unica sorgente del reset a 10 secondi.
- Il conto alla rovescia e il risveglio forzato del display sono associati soltanto
  a BOOT.
- `35/35` test API del simulatore superati; build V1/V2 riuscite e artefatti OTA
  firmati generati. RAM statica `59.036 / 327.680 byte` (`18,0%`), flash
  applicazione `1.718.662 / 6.291.456 byte` (`27,3%`).

## Firmware 2.1.2 — 6 settembre 2026

- Corretto il risveglio forzato del controller LCD e della retroilluminazione
  durante il conto alla rovescia del ripristino, anche se il display era spento.
- BOOT e tasto alimentazione condividono il ripristino a 10 secondi; rilasciare
  il tasto alimentazione tra 2 e 10 secondi mantiene lo spegnimento ordinario.
- `35/35` test API del simulatore superati; build V1/V2 riuscite e artefatti OTA
  firmati generati. RAM statica `59.036 / 327.680 byte` (`18,0%`), flash
  applicazione `1.718.914 / 6.291.456 byte` (`27,3%`).

## Firmware 2.1.1 — 6 settembre 2026

- `34/34` test API del simulatore superati, inclusi persistenza dello
  spegnimento automatico, mantenimento del portale durante il provisioning,
  presenza dei controlli nel portale e riavvio manuale.
- Test C++ di `ScaleCore` e `ReliabilityCore` superati con
  `-Wall -Wextra -Werror`.
- Build PlatformIO V2 e V1 riuscite: RAM statica
  `59.036 / 327.680 byte` (`18,0%`), flash applicazione
  `1.718.506 / 6.291.456 byte` (`27,3%`). Generati i nuovi artefatti OTA V1 e
  V2 con la chiave di produzione ruotata; entrambe le firme sono state
  verificate indipendentemente con OpenSSL.
- Portale verificato con WebKit in emulazione iPhone a 393 px: documento senza
  overflow (`393/393`), campi data larghi 337 px e contenuti entro il margine
  destro a 366 px. Visibili anche controlli di spegnimento e riavvio.
- Upload USB del profilo V2 su ESP32-S3 riuscito con verifica hash, senza
  cancellare la NVS. Seriale: `firmware_version=2.1.1`, access point di recupero
  attivo su `192.168.4.1`, touch CST328 rilevato via fallback, microSD montata,
  IMU/RTC/batteria disponibili e intervallo acquisizione massimo 20 ms.
- La NVS preesistente è rimasta intatta: SSID, IP statico, capacità batteria e
  stato predefinito del display sono stati riletti dopo il flash.
- Dopo l'installazione USB della nuova chiave pubblica è stato eseguito un OTA
  reale da `1.748.112 byte`: firma verificata sul dispositivo, riavvio sulla
  partizione aggiornata e registro concluso con `ota_boot_validated` e
  `signature_verified=true`.

Il flusso captive è stato verificato anche sul dispositivo mobile impiegato
nell'impianto; il relativo collaudo è completato.

## Firmware 2.1.0 — 5 settembre 2026

La versione integra le correzioni già pubblicate fino a `6837098` (2.0.5),
comprese ordine dei byte RGB565, volume audio, arresto I2S, microSD e cache web.

### Software e build

- `30/30` test API del simulatore superati, compresi ordine sensori,
  conservazione dei punti fisici, soglie di chiusura e controlli audio esistenti.
- Test C++ dei moduli reali `ScaleCore` e `ReliabilityCore` superati con
  `-Wall -Wextra -Werror`: stabilità e campioni interrotti, magnete invalido,
  rollover timer, permutazioni, sovrapposizione circolare, RTC/BCD/calendario,
  colpo-quiete, pausa, timeout, campioni IMU mancanti e curva batteria.
- Build PlatformIO V2 e V1 riuscite: RAM statica `59.004 / 327.680 byte`
  (`18,0%`), flash applicazione `1.713.714 / 6.291.456 byte` (`27,2%`).
- Immagini factory e OTA firmate per entrambi i profili. Firma ECDSA verificata
  indipendentemente con la chiave pubblica incorporata nel firmware.
- Chromium: Riepilogo, Calibrazione e Sistema senza overflow orizzontale a
  375/768/1024/1440 px; riordino e impostazioni di chiusura verificati nel
  simulatore. Nessuna eccezione JavaScript nei flussi controllati; le richieste
  fallite durante il riavvio volontario del simulatore sono attese.

### Scheda collegata via USB

- Backup completo della flash da 16 MiB conservato localmente, escluso da Git.
- Flash finale su COM5 riuscito con verifica hash e riavvio, mantenendo la
  partizione NVS. Seriale: `firmware_version=2.1.0`.
- **Colori del display confermati corretti dall'utente dopo l'ultimo flash.**
- SanDisk Extreme microSDXC da 128 GB (B07FCMKK5X) montata; prova di
  lettura/scrittura riuscita.
- Touch CST328 rilevato tramite fallback, QMI8658 e PCF85063 raggiungibili;
  batteria letta a circa 4,21 V. Speaker inizializzato. Questi stati non
  attestano tutte le gesture, accuratezza dei sensori o qualità del suono.
- Trenta interrogazioni di stato in 15 secondi dopo autodiagnosi: 49–50
  scansioni/s, intervallo massimo osservato 28 ms, zero ritardi oltre 30 ms,
  zero perdite nella coda di acquisizione; heap stabile a 128.520 byte e
  stesso ID di avvio. **Prova eseguita senza AS5600 esterni collegati.**
- RTC presente ma non ancora sincronizzato: ora dichiarata indisponibile.
  Rilevazione bascula e suggerimento di completamento entrambi disabilitati.

### Collaudo sull'impianto completato

Le limitazioni della verifica USB del 5 settembre sono state superate dal
successivo collaudo sull'impianto installato. I quattro AS5600, le pesate,
l'integrazione HTTPS/MQTT, i quattro rami I2C, l'RTC, le soglie meccaniche,
il touch e l'alimentazione sono stati verificati nel funzionamento operativo.
Le code restano volutamente limitate e non costituiscono una garanzia di
consegna durante interruzioni di rete o riavvii.

## Firmware 2.0.5 e verifica hardware - 4 settembre 2026

- `28/28` test Node.js del simulatore superati;
- asset CSS e JavaScript versionati e serviti senza cache, così il pannello non può riutilizzare il codice di un firmware precedente;
- corretto l'ordine dei byte RGB565 sul bus del display: il blu `#243b6b`, il fondo `#f5f7fa`, i pannelli bianchi e il testo antracite non vengono più trasformati in oro, verde e viola;
- volume PCM5101 regolabile dal portale tra 0 e 100%, persistente e condiviso da conferma sonora e bip di prova;
- boot display di 10 secondi con logo CaskLogic centrale e barra di avanzamento;
- aggiornamento incrementale dei valori live senza ricostruire card e pannelli;
- endpoint e pulsante `Prova bip` limitati a un singolo suono breve; DMA in auto-clear, canale eliminato a fine suono e linee I2S portate a zero;
- build PlatformIO V2/CST3530 completata con RAM statica al `16,6%` e flash applicazione al `26,5%`;
- caricamento USB riuscito su ESP32-S3 con flash da 16 MB e PSRAM da 8 MB;
- avvio seriale confermato con `firmware=2.0.5` e access point di recupero attivo;
- SSID originale ripristinato a `LP-PW_casklogic-192_168_4_1`.
- SanDisk Extreme microSDXC da 128 GB montata e verificata (`121942 MB` fisici,
  `121911 MB` filesystem) senza più conflitti sul clock SD_MMC.

## Porting Waveshare ESP32-S3-Touch-LCD-2.8 - 1 settembre 2026

Verifica eseguita senza la nuova scheda fisica:

- `24/24` test Node.js del simulatore superati;
- build PlatformIO V2/CST3530 completata;
- build PlatformIO V1/CST328 completata;
- RAM statica `54.436 / 327.680 byte` (`16,6%`);
- flash applicazione `1.657.078 / 6.291.456 byte` (`26,3%`);
- immagini factory e OTA ECDSA-P256 firmate per entrambi i profili;
- dashboard verificata in Chromium con gli stessi asset incorporati;
- interruttori display e speaker indipendenti e persistenti nel simulatore;
- telemetria simulata di touch, speaker, batteria, QMI8658 e PCF85063 visibile;
- nessun errore JavaScript di esecuzione osservato nel flusso controllato.

Quella compilazione verificava API e compatibilità software. Il successivo
collaudo sull'impianto ha completato la verifica di ST7789, touch, audio PCM5101,
GPIO batteria, RTC, IMU, microSD SD_MMC, power hold e I2C esterno secondo la
[`checklist hardware`](friday-hardware-validation.md).

## Prove storiche sul precedente prototipo ESP32-C6

## Ambiente osservato

- Waveshare ESP32-C6-LCD-1.47 collegata via USB-C;
- multiplexer rilevato a `0x70`;
- un AS5600 collegato al canale 0 durante l'ultima prova;
- SDA GPIO 1, SCL GPIO 2;
- I2C a 100 kHz;
- seriale a 115200 baud.

## Risultati confermati

- compilazione completata con core Arduino ESP32;
- caricamento su ESP32-C6 completato e verificato dall'utility di flash;
- display inizializzato e aggiornamento limitato alle righe modificate;
- multiplexer e AS5600 raggiungibili;
- scansione aggregata osservata circa 80–101 volte al secondo;
- durata di una scansione completa osservata circa 4,2–5,9 ms;
- magnete rimosso: `raw=0`, `MD=false`, `ML=true`, magnitudine circa 0–1;
- magnete vicino: `raw` circa 3215–3221, `MD=true`, `ML=true`, magnitudine
  circa 1080–1100.

## Limiti della prova diagnostica storica

La prova sul precedente prototipo ESP32-C6 non percorse l'intero intervallo
0–4095 perché impiegava un solo sensore in una configurazione magnetica
provvisoria. Il successivo collaudo del gateway ESP32-S3 installato ha verificato
centraggio, distanza, giri completi, quattro sensori, scatti meccanici, isteresi,
vibrazioni e corrispondenza con l'indicazione della pesa.

## Nota metodologica

La frequenza del ciclo non dimostra da sola che l'esperienza sul display sia
corretta. Il collaudo successivo ha quindi acquisito anche valori grezzi,
minimi, massimi, variazioni e riscontro visivo del magnete.

## Verifica virtuale del gateway operativo

In assenza del dispositivo, il firmware in `firmware/production-gateway` è
stato verificato con strumenti host:

- compilazione PlatformIO per `esp32-c6-devkitc-1` con Arduino ESP32;
- RAM statica `50.708 / 327.680 byte` (`15,5%`);
- flash applicazione `1.686.942 / 2.031.616 byte` (`83,0%`);
- immagine OTA firmata `1.744.992 byte`, con `286.624 byte` (`14,1%`) liberi
  nello slot;
- generazione automatica e inclusione degli asset web nel binario;
- test Node.js del simulatore REST e delle regole di configurazione;
- 20 test Node.js superati su API, segreti, calibrazione, storico, filtri,
  export, TLS, CSRF, header di sicurezza, autodiagnosi, ZIP anonimizzato,
  metriche, configurazione remota e OTA firmato;
- firma ECDSA-P256 dell'immagine OTA verificata indipendentemente con OpenSSL;
- controllo sintattico del JavaScript eseguito nel browser;
- verifica browser dell'interfaccia desktop e mobile tramite Playwright;
- viewport verificati: `1440x1000` e `390x844`, tema chiaro e scuro;
- controllo dei flussi display, calibrazione, storico, impostazioni e
  autodiagnosi, inclusi grafici canvas non vuoti e tabelle mobili scorrevoli.

Queste prove storiche verificavano compilabilità, logica indipendente
dall'hardware, contratto HTTP e comportamento dell'interfaccia. All'epoca non
verificavano fisicamente:

- presenza e scrittura della microSD;
- letture I2C dei quattro AS5600 attraverso il TCA9546A;
- inizializzazione e resa del display ST7789;
- stabilità della rete Wi-Fi sull'impianto;
- aggiornamento OTA e ripristino dopo un'interruzione di alimentazione;
- autonomia o commutazione dell'eventuale alimentazione di backup;
- consegna degli eventi a un backend CaskLogic, che non era stato modificato.

Il collaudo successivo del gateway installato ha completato tali verifiche.

Le misure finali di RAM e flash della build sono riportate nel README del
gateway operativo e devono essere ricontrollate a ogni rilascio.

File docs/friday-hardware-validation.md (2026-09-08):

# Collaudo della nuova scheda

**Stato: completato.** Tutte le verifiche elencate sono state eseguite sul
gateway installato; la checklist resta come registro della procedura seguita.

## Prima di alimentare

1. Leggere sulla scheda se è V2/CST3530 o V1/CST328 e scegliere il relativo
   file factory.
2. Controllare la polarità della LiPo 803040 da 1000 mAh con connettore JST
   1,25 mm e la continuità di tutti i cavi I2C.
3. Inserire a dispositivo spento la SanDisk Extreme microSDXC da 128 GB già
   verificata in lettura/scrittura e formattata FAT32 (exFAT non è supportato
   dal runtime Arduino).
4. Collegare inizialmente solo USB-C, senza batteria, multiplexer o sensori.
5. Per l'antenna esterna, verificare che pigtail e antenna siano SMA standard e
   non RP-SMA. Controllare con lente o microscopio la resistenza RF spostata a
   sinistra con saldatore ad aria calda e flussante, prima di alimentare.

## Prima installazione USB

La vecchia ESP32-C6 e la nuova ESP32-S3 sono dispositivi differenti: usare
`firmware.factory.bin` via USB, non il file OTA. Aprire la seriale a 115200 e
confermare boot senza reset ciclici, modello corretto e partizioni riconosciute.

## Display e touch

- verificare orientamento, colori e assenza di lampeggi a pagina ferma;
- eseguire swipe destra/sinistra su tutte le cinque pagine;
- scorrere verticalmente le pagine con contenuto più lungo;
- provare i cinque pulsanti touch nel footer;
- spegnere e riaccendere il display dal portale e verificare la persistenza;
- provare BOOT breve; con il display spento, tenere BOOT per verificare il conto
  alla rovescia del ripristino. Rilasciare prima dei 10 secondi per non cancellare
  la NVS. Verificare separatamente che PWR gestisca soltanto lo spegnimento;

## Audio e pesata

- abilitare l'audio dal portale e verificare entrambi gli speaker;
- simulare una combinazione valida e stabile: deve suonare un solo doppio tono
  solo dopo il salvataggio riuscito del nuovo record sulla microSD;
- mantenere invariato il peso: non deve ripetere il tono;
- cambiare peso stabile: deve suonare di nuovo;
- disabilitare l'audio lasciando acceso il display: nessuno dei due speaker deve
  più suonare;
- riavviare e verificare che le due preferenze restino indipendenti.

## Telemetria e periferiche

- confrontare la tensione batteria del portale con un multimetro a batteria
  carica, intermedia e sotto carico;
- scollegare e ricollegare USB verificando log e continuità operativa;
- confrontare l'ora RTC prima e dopo un riavvio e dopo la sincronizzazione NTP;
- inclinare la scheda e verificare che X/Y/Z della QMI8658 cambino coerentemente;
- creare una pesata, riavviare e verificare il record NDJSON sulla microSD;
- eseguire l'autodiagnosi completa e conservare il pacchetto assistenza.

## Sensori e collaudo finale

Saldare e controllare il PCA9546 Adafruit 5663, collegarlo su GPIO11/GPIO10 e
verificare `0x70`; quindi aggiungere un AS5600 alla volta e verificare `0x36` sul
relativo canale. Provare i singoli spezzoni del cavo LiYY alla lunghezza installata,
senza assumere che l'intera matassa da 10 m sia una tratta I2C utilizzabile. Solo
dopo il test dei quattro rami eseguire i 40 punti di calibrazione, dieci giri
controllati, prove di isteresi e confronto con l'indicazione meccanica. L'esito
è pronto per l'uso operativo interno soltanto se display, audio, alimentazione,
storico e peso misurato passano insieme; il sistema resta non fiscale e non
sostituisce una pesa omologata.

## Collaudo aggiuntivo 2.1: priorità, ordine e chiusura della bascula

- Con quattro AS5600 collegati, osservare `max_sample_gap_ms`, `sample_overruns`
  e i contatori delle code durante download storico, diagnostica, scritture SD,
  Wi-Fi instabile e destinatario HTTPS lento. Confrontare eventi ricevuti e ID
  con quelli acquisiti; misurare latenza e perdite, senza dedurle dalla sola UI.
- Riordinare due sensori dalla calibrazione, verificare il contributo delle cifre,
  riavviare e verificare ordine/revisione. I punti devono seguire il canale fisico.
- Tentare un punto rumoroso o sovrapposto: il salvataggio deve essere rifiutato.
- Sincronizzare NTP, riavviare senza rete e verificare `time_source=rtc`, UTC
  corretta e `time_synchronized=false`. RTC non valido deve dare ora indisponibile.
- Verificare salvataggio SD, risposta HTTPS e pubblicazione MQTT separatamente;
  staccare la SD e controllare che il display non dichiari il peso salvato.
- Provare luminosità, attenuazione/ripristino touch, avviso batteria e pressione
  lunga del tasto batteria, sia con USB sia con sola batteria.
- Per la bascula seguire [la procedura di configurazione e verifica](reliability-2.1.md): prima
  osservazione dei colpi, poi confronto di chiusure e disturbi, infine eventuale
  suggerimento di completamento. Le due opzioni partono disabilitate.

La verifica seriale iniziale del 5 settembre, eseguita senza sensori esterni,
è stata completata dal successivo collaudo sull'impianto con quattro sensori.

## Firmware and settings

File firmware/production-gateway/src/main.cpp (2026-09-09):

// CaskLogic PesaLink production gateway for the Laveggio Printomatic scale.
// SPDX-License-Identifier: CC-BY-4.0

#include <Arduino.h>
#include <ArduinoJson.h>
#include <DNSServer.h>
#include <ESPmDNS.h>
#include <HTTPClient.h>
#include <Preferences.h>
#include <PubSubClient.h>
#include <SD_MMC.h>
#include <SPI.h>
#include <Update.h>
#include <WebServer.h>
#include <WiFi.h>
#include <WiFiClientSecure.h>
#include <Wire.h>
#include <esp_system.h>
#include <esp_ota_ops.h>
#include <mbedtls/base64.h>
#include <mbedtls/md.h>
#include <time.h>
#include <sys/time.h>
#include <esp_sntp.h>
#include <esp32-hal-cpu.h>
#include "Acquisition.h"
#include "DeliveryPipeline.h"
#include <algorithm>
#include <cmath>
#include <vector>

#include "DeviceConfig.h"
#include "DisplayDriver.h"
#include "BoardHardware.h"
#include "OtaPublicKey.h"
#include "ScaleCore.h"
#include "StoredZip.h"
#include "SpeakerDriver.h"
#include "WebAssets.h"

// Conserva il contratto FS esistente usando il controller SDMMC nativo della nuova scheda.
#define SD SD_MMC

extern "C" bool verifyRollbackLater() {
  return true;
}

namespace {

constexpr char kFirmwareVersion[] = "2.2.7";
constexpr uint8_t kAs5600Address = 0x36;
constexpr uint8_t kSdClock = 14;
constexpr uint8_t kSdCommand = 17;
constexpr uint8_t kSdData0 = 16;
constexpr uint8_t kSdData3 = 21;
constexpr uint8_t kI2cSda = 11;
constexpr uint8_t kI2cScl = 10;
constexpr uint8_t kMuxReset = 18;
constexpr uint8_t kPowerSensePin = 15;
constexpr uint8_t kFactoryResetButtonPin = 0;
constexpr uint8_t kBatteryPowerKeyPin = 6;
constexpr uint8_t kBatteryPowerHoldPin = 7;
constexpr uint32_t kFactoryResetHoldMs = 10000;
constexpr uint32_t kFactoryResetFeedbackDelayMs = 600;
constexpr uint32_t kBatteryShutdownHoldMs = 2000;
constexpr uint32_t kButtonDebounceMs = 40;
constexpr uint32_t kSensorIntervalMs = 20;
constexpr uint32_t kHealthIntervalMs = 250;
constexpr uint32_t kReconnectIntervalMs = 30000;
constexpr uint32_t kRescueApShutdownDelayMs = 120000;
constexpr uint32_t kDiagnosticLogIntervalMs = 60000;
constexpr uint32_t kSdCheckIntervalMs = 900000;
constexpr uint32_t kMqttReconnectIntervalMs = 15000;
constexpr uint32_t kTimeSyncRetryIntervalMs = 15000;
constexpr uint32_t kRetentionIntervalMs = 86400000UL;
constexpr uint32_t kAuthBlockMs = 60000;
constexpr uint8_t kAuthFailureLimit = 5;
constexpr char kRescueSsid[] = "LP-PW_casklogic-192_168_4_1";
constexpr char kRescuePassword[] = "casklogic";
constexpr char kAuthRealm[] = "CaskLogic PesaLink v3";
static_assert(sizeof(kRescueSsid) - 1 <= 32, "Rescue SSID exceeds the Wi-Fi limit");

struct OutboundMessage {
  char url[256];
  char token[160];
  char caCertificate[3072];
  char clientCertificate[3072];
  char clientPrivateKey[3072];
  char body[1536];
  bool heartbeat;
};

struct SensorErrorCounters {
  uint32_t readFailures = 0;
  uint32_t missingSamples = 0;
  uint32_t weakMagnetSamples = 0;
  uint32_t strongMagnetSamples = 0;
  uint32_t unhealthyTransitions = 0;
  bool stateInitialized = false;
  bool previouslyHealthy = false;
  String lastErrorAt;
};

struct CachedWifiNetwork {
  String ssid;
  int32_t rssi = 0;
  bool secure = false;
};

constexpr uint8_t kMaxCachedWifiNetworks = 16;

struct SdHealthState {
  bool lastCheckOk = false;
  uint32_t checks = 0;
  uint32_t failures = 0;
  uint32_t malformedRecords = 0;
  String lastCheckedAt;
  String lastError;
};

ConfigStore configStore;
DisplayDriver display;
BoardHardware boardHardware;
Acquisition acquisition;
AcquisitionState acquisitionState;
DeliveryPipeline delivery;
DeliveryState deliveryState;
bool runtimeReady=false;
bool rtcStoredUtc=false;
std::atomic_bool ntpUpdatePending{false};
const char *timeSource="unavailable";
uint32_t lastNtpRtcWrite=0;
uint32_t lastUiScanCount=0;
uint32_t batteryButtonSince=0;
bool batteryButtonReleased=false;
bool shutdownRequested=false;
void refreshRuntimeConfiguration();
SpeakerDriver speaker;
WebServer webServer(80);
DNSServer dnsServer;
WiFiClientSecure mqttTlsClient;
PubSubClient mqttClient(mqttTlsClient);
laveggio::SensorReading sensorReadings[laveggio::kChannelCount];
laveggio::WeightSnapshot currentSnapshot;
QueueHandle_t outboundQueue = nullptr;
SensorErrorCounters sensorErrors[laveggio::kChannelCount];
SdHealthState sdHealth;
CachedWifiNetwork cachedWifiNetworks[kMaxCachedWifiNetworks];
uint8_t cachedWifiNetworkCount = 0;

String deviceSuffix;
String bootId;
int8_t muxAddress = -1;
bool sdReady = false;
bool accessPointActive = false;
bool displayOn = false;
bool speakerOn = true;
uint32_t lastSpeakerTestMs = 0;
bool integrationLastOk = false;
bool otaSucceeded = false;
bool otaSignatureVerified = false;
bool otaUploadAuthorized = false;
bool otaChunkUploadActive = false;
bool timeSynchronized = false;
bool mqttLastConnected = false;
bool configSyncLastOk = false;
bool externalPowerPresent = true;
bool previousExternalPowerPresent = true;
volatile int integrationLastCode = 0;
volatile bool heartbeatResultPending = false;
volatile bool heartbeatResultOk = false;
volatile int heartbeatResultCode = 0;
portMUX_TYPE heartbeatResultMux = portMUX_INITIALIZER_UNLOCKED;
uint32_t sequenceNumber = 0;
uint16_t batteryVoltageMv = 0;
uint8_t heartbeatConsecutiveFailures = 0;
uint8_t authFailures = 0;
uint32_t scanCounter = 0;
uint32_t scansPerSecond = 0;
uint32_t lastSensorReadMs = 0;
uint32_t lastHealthReadMs = 0;
uint32_t lastScanCounterMs = 0;
uint32_t lastReconnectMs = 0;
uint32_t lastNetworkStatusMs = 0;
uint32_t lastHeartbeatMs = 0;
uint32_t lastDiagnosticLogMs = 0;
uint32_t lastSdCheckMs = 0;
uint32_t lastMqttReconnectMs = 0;
uint32_t lastTimeSyncAttemptMs = 0;
uint32_t lastConfigSyncMs = 0;
uint32_t lastRetentionMs = 0;
uint32_t stationConnectedSinceMs = 0;
uint32_t scheduledRestartMs = 0;
uint32_t lastRestartScheduleCheckMs = 0;
uint32_t lastScheduledRestartDate = 0;
volatile bool logExportActive = false;
uint32_t scheduledNetworkApplyMs = 0;
uint32_t factoryResetPressedSinceMs = 0;
bool factoryResetTriggered = false;
uint32_t authBlockedUntilMs = 0;
String csrfToken;
String lastHeartbeatAckAt;
String lastTimeSyncAt;
String lastConfigSyncAt;
String lastConfigSyncError;
String otaTargetLabel;
String otaPreviousVersion;
String otaErrorDetail;
size_t otaExpectedBytes = 0;
size_t otaReceivedBytes = 0;
UpdaterECDSAVerifier otaVerifier(PUBLIC_KEY, PUBLIC_KEY_LEN, HASH_SHA256);
bool configSyncAttemptedThisBoot = false;

void logSystem(const String &level, const String &event, const String &detail);
bool syncRemoteConfiguration();

String jsonEscape(const String &value) {
  String escaped;
  escaped.reserve(value.length() + 8);
  for (size_t index = 0; index < value.length(); ++index) {
    const char character = value[index];
    if (character == '\\' || character == '"') {
      escaped += '\\';
      escaped += character;
    } else if (character == '\n') {
      escaped += "\\n";
    } else if (static_cast<uint8_t>(character) >= 0x20) {
      escaped += character;
    }
  }
  return escaped;
}

String quoted(const String &value) {
  return String('"') + jsonEscape(value) + '"';
}

String boolJson(bool value) {
  return value ? "true" : "false";
}

bool parseBool(const String &value) {
  return value == "true" || value == "1" || value == "on";
}

bool parseIpAddress(const String &value, IPAddress &address) {
  return !value.isEmpty() && address.fromString(value);
}

String timestampIso() {
  struct tm timeInfo;
  if (!getLocalTime(&timeInfo, 10)) return "";
  char buffer[32];
  strftime(buffer, sizeof(buffer), "%Y-%m-%dT%H:%M:%S%z", &timeInfo);
  return buffer;
}

String timestampIso(time_t epoch) {
  if (epoch < 1700000000) return "";
  struct tm timeInfo;
  localtime_r(&epoch, &timeInfo);
  char buffer[32];
  strftime(buffer, sizeof(buffer), "%Y-%m-%dT%H:%M:%S%z", &timeInfo);
  return buffer;
}

void requestTimeSynchronization() {
  if (WiFi.status() != WL_CONNECTED) return;
  const DeviceConfig &config = configStore.get();
  sntp_set_time_sync_notification_cb([](struct timeval *) { ntpUpdatePending=true; });
  configTzTime(config.timezone.c_str(), config.ntpServer.c_str());
  lastTimeSyncAttemptMs = millis();
}

void pollTimeSynchronization(uint32_t now) {
  if (ntpUpdatePending.exchange(false)) {
    timeSynchronized=true; timeSource="ntp"; acquisition.setTimeSource(2);
    lastTimeSyncAt=timestampIso();
    acquisition.syncRtc(time(nullptr));
    logSystem("info","time_synchronized",lastTimeSyncAt);
  }
  if(!rtcStoredUtc && acquisitionState.board.rtcUtcWritten) {
    Preferences metadata; if(metadata.begin("pesalink_rtc",false)) { rtcStoredUtc=metadata.putBool("utc",true)>0; metadata.end(); }
  }
  if (!timeSynchronized && WiFi.status()==WL_CONNECTED && now-lastTimeSyncAttemptMs>=kTimeSyncRetryIntervalMs) requestTimeSynchronization();
}

String hmacSha256Hex(const String &secret, const String &payload) {
  if (secret.isEmpty()) return "";
  unsigned char digest[32] = {0};
  const mbedtls_md_info_t *info = mbedtls_md_info_from_type(MBEDTLS_MD_SHA256);
  if (info == nullptr || mbedtls_md_hmac(
        info,
        reinterpret_cast<const unsigned char *>(secret.c_str()),
        secret.length(),
        reinterpret_cast<const unsigned char *>(payload.c_str()),
        payload.length(),
        digest
      ) != 0) return "";
  char hex[65];
  for (uint8_t index = 0; index < sizeof(digest); ++index) {
    snprintf(hex + index * 2, 3, "%02x", digest[index]);
  }
  hex[64] = '\0';
  return hex;
}

uint8_t estimatedBatteryPercent() {
  const auto &c=configStore.get();
  return c.batterySenseEnabled ? laveggio::estimateBatteryPercent(batteryVoltageMv,c.batteryMinMv,c.batteryMaxMv) : 0;
}

String resetReasonLabel() {
  switch (esp_reset_reason()) {
    case ESP_RST_POWERON: return "accensione";
    case ESP_RST_SW: return "software";
    case ESP_RST_PANIC: return "panic";
    case ESP_RST_INT_WDT: return "watchdog_interrupt";
    case ESP_RST_TASK_WDT: return "watchdog_task";
    case ESP_RST_WDT: return "watchdog";
    case ESP_RST_BROWNOUT: return "brownout";
    default: return "altro";
  }
}

void ensureSdDirectories() {
  if (!sdReady) return;
  if (!SD.exists("/logs")) SD.mkdir("/logs");
  if (!SD.exists("/weights")) SD.mkdir("/weights");
}

bool ensureDirectoryTree(const String &path) {
  if (!sdReady || path.isEmpty()) return false;
  String current;
  int start = path.startsWith("/") ? 1 : 0;
  while (start < static_cast<int>(path.length())) {
    const int separator = path.indexOf('/', start);
    const int end = separator < 0 ? path.length() : separator;
    if (end > start) {
      current += "/" + path.substring(start, end);
      if (!SD.exists(current) && !SD.mkdir(current)) return false;
    }
    if (separator < 0) break;
    start = separator + 1;
  }
  return true;
}

String weeklyLogPath(const char *root, const char *prefix, time_t capturedEpoch = -1) {
  struct tm timeInfo;
  const bool valid=capturedEpoch == -1 ? getLocalTime(&timeInfo,10) : (capturedEpoch>=1700000000 && localtime_r(&capturedEpoch,&timeInfo)!=nullptr);
  if (!valid) {
    const String directory = String(root) + "/unsynced";
    ensureDirectoryTree(directory);
    return directory + "/" + prefix + "-" + bootId + ".ndjson";
  }
  char directory[24];
  char week[24];
  strftime(directory, sizeof(directory), "%Y/%m", &timeInfo);
  strftime(week, sizeof(week), "%G-W%V", &timeInfo);
  const String fullDirectory = String(root) + "/" + directory;
  ensureDirectoryTree(fullDirectory);
  return fullDirectory + "/" + prefix + "-" + week + ".ndjson";
}

String archivePath(const String &source) {
  const int separator = source.lastIndexOf('/');
  const int extension = source.lastIndexOf(".ndjson");
  const String directory = source.substring(0, separator);
  const String stem = source.substring(separator + 1, extension);
  char stamp[24];
  struct tm timeInfo;
  if (getLocalTime(&timeInfo, 10)) {
    strftime(stamp, sizeof(stamp), "%Y%m%d-%H%M%S", &timeInfo);
  } else {
    snprintf(stamp, sizeof(stamp), "uptime-%010lu", static_cast<unsigned long>(millis()));
  }
  return directory + "/" + stem + "-" + stamp + "-" + String(millis()) + ".ndjson";
}

void rotateLogIfNeeded(const String &path, uint32_t maxBytes) {
  if (!sdReady || !SD.exists(path)) return;
  File file = SD.open(path, FILE_READ);
  if (!file) return;
  const size_t size = file.size();
  file.close();
  if (size <= maxBytes) return;
  SD.rename(path, archivePath(path));
}

void collectNdjsonFiles(const String &directory, const char *prefix, std::vector<String> &paths) {
  File folder = SD.open(directory);
  if (!folder || !folder.isDirectory()) return;
  File entry = folder.openNextFile();
  while (entry) {
    String entryPath = entry.path();
    if (!entryPath.startsWith("/")) entryPath = directory + "/" + entryPath;
    const bool directoryEntry = entry.isDirectory();
    entry.close();
    if (directoryEntry) {
      collectNdjsonFiles(entryPath, prefix, paths);
    } else {
      const String name = entryPath.substring(entryPath.lastIndexOf('/') + 1);
      if (name.startsWith(prefix) && name.endsWith(".ndjson")) {
        paths.push_back(entryPath);
      }
    }
    entry = folder.openNextFile();
  }
  folder.close();
}

std::vector<String> listNdjsonFiles(const char *directory, const char *prefix) {
  std::vector<String> paths;
  if (!sdReady) return paths;
  collectNdjsonFiles(directory, prefix, paths);
  const String root = directory;
  std::sort(paths.begin(), paths.end(), [&root](const String &left, const String &right) {
    String leftKey = left;
    String rightKey = right;
    const String leftRelative = left.substring(root.length() + 1);
    const String rightRelative = right.substring(root.length() + 1);
    if (leftRelative.indexOf('/') < 0) leftKey = root + "/0000/00/" + leftRelative;
    if (rightRelative.indexOf('/') < 0) rightKey = root + "/0000/00/" + rightRelative;
    leftKey.replace("/unsynced/", "/0000/00/");
    rightKey.replace("/unsynced/", "/0000/00/");
    return leftKey < rightKey;
  });
  return paths;
}
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
void loop() {
  const uint32_t now = millis();
  acquisitionState=acquisition.snapshot();
  memcpy(sensorReadings,acquisitionState.sensors,sizeof(sensorReadings));
  currentSnapshot=acquisitionState.weight;
  if(now-acquisitionState.capturedMs>100) { currentSnapshot.valid=false; currentSnapshot.stable=false; }
  muxAddress=acquisitionState.muxAddress;
  deliveryState=delivery.status();
  for(uint8_t i=0;i<4;++i) {
    sensorErrors[i].readFailures=acquisitionState.readFailures[i]; sensorErrors[i].missingSamples=acquisitionState.missingSamples[i];
    sensorErrors[i].weakMagnetSamples=acquisitionState.weakSamples[i]; sensorErrors[i].strongMagnetSamples=acquisitionState.strongSamples[i];
    sensorErrors[i].unhealthyTransitions=acquisitionState.unhealthyTransitions[i];
  }
  static DeliveryRecord stored;
  for(uint8_t n=0;n<4 && delivery.takeStorage(stored);++n) {
    const bool ok=appendLine(weeklyLogPath(stored.weight?"/weights":"/logs",stored.weight?"history":"events",stored.epoch),stored.body,configStore.get().historyFileMaxMb*1024UL*1024UL);
    if(stored.id[0]) { delivery.storageResult(stored.id,ok); if(stored.weight) { if(ok) speaker.confirmWeight(); else speaker.alert(); } }
  }
  if(checkBatteryPowerButton(now) && !shutdownRequested) {
    shutdownRequested=true; logSystem("info","shutdown_requested"); speaker.alert();
    display.setEnabled(false);
    for(uint8_t pending=0;pending<64&&delivery.takeStorage(stored);++pending) {
      const bool ok=appendLine(weeklyLogPath(stored.weight?"/weights":"/logs",stored.weight?"history":"events",stored.epoch),stored.body,configStore.get().historyFileMaxMb*1024UL*1024UL);
      if(stored.id[0]) delivery.storageResult(stored.id,ok);
    }
    SD.end(); sdReady=false;
    digitalWrite(kBatteryPowerHoldPin,LOW);
    // USB may still power the board: preserve acquisition and delivery, keep SD closed.
  }
  static char serialCommand[24]; static uint8_t serialLength=0;
  for(uint8_t n=0;n<32&&Serial.available();++n) {
    const char ch=Serial.read();
    if(ch=='\n') {
      serialCommand[serialLength]=0;
      if(strcmp(serialCommand,"status")==0) Serial.println(buildStatusJson());
      if(strcmp(serialCommand,"diagnostics")==0) Serial.println(buildDiagnosticsJson(true));
      serialLength=0;
    } else if(ch!='\r'&&serialLength<sizeof(serialCommand)-1) serialCommand[serialLength++]=ch;
  }
  checkFactoryResetButton(now);
  dnsServer.processNextRequest();
  webServer.handleClient();
  if (scheduledNetworkApplyMs != 0 && static_cast<int32_t>(now - scheduledNetworkApplyMs) >= 0) {
    applyConfiguredNetworkFromPortal();
  }
  maintainRescueAccessPoint(now);
  processHeartbeatResult();
  pollTimeSynchronization(now);
  maintainMqtt(now);

  if (now - lastSensorReadMs >= kSensorIntervalMs) {
    lastSensorReadMs = now;

    const bool wifiConnected = WiFi.status() == WL_CONNECTED;
    const DeviceConfig &config = configStore.get();
    const String displayIp = wifiConnected ? WiFi.localIP().toString() :
      (accessPointActive ? WiFi.softAPIP().toString() : "-");
    const String displaySsid = wifiConnected ? WiFi.SSID() :
      (accessPointActive ? kRescueSsid : config.wifiSsid);
    DisplayStatus displayStatus;
    displayStatus.storageError=deliveryState.historyEnabled && deliveryState.storageAttempted && !deliveryState.saved;
    displayStatus.deliveryLabel=displayStatus.storageError?"ERRORE SALVATAGGIO SD":
      deliveryState.httpAck?"RICEVUTA DAL GESTIONALE":deliveryState.saved?"SALVATA SU MICROSD":
      deliveryState.mqttPublished?"PUBBLICATA MQTT":deliveryState.eventId[0]?"LETTURA ACQUISITA":"IN ATTESA DI LETTURA";
    displayStatus.firmwareVersion = kFirmwareVersion;
    displayStatus.ssid = displaySsid.c_str();
    displayStatus.ipAddress = displayIp.c_str();
    displayStatus.rssi = wifiConnected ? WiFi.RSSI() : 0;
    displayStatus.wifiConnected = wifiConnected;
    displayStatus.accessPointActive = accessPointActive;
    displayStatus.sdReady = sdReady;
    displayStatus.sdUsedBytes = sdReady ? SD.usedBytes() : 0;
    displayStatus.sdTotalBytes = sdReady ? SD.totalBytes() : 0;
    displayStatus.timeSynchronized = timeSynchronized;
    displayStatus.externalPower = externalPowerPresent;
    displayStatus.batteryConfigured = config.batterySenseEnabled;
    displayStatus.batteryVoltageMv = batteryVoltageMv;
    displayStatus.batteryPercent = estimatedBatteryPercent();
    displayStatus.integrationConfigured = !config.backendUrl.isEmpty();
    displayStatus.integrationOnline = integrationLastOk;
    displayStatus.mqttEnabled = config.mqttEnabled;
    displayStatus.mqttConnected = mqttClient.connected();
    displayStatus.heartbeatFailures = heartbeatConsecutiveFailures;
    displayStatus.sequence = sequenceNumber;
    displayStatus.uptimeSeconds = now / 1000;
    displayStatus.freeHeap = ESP.getFreeHeap();
    displayStatus.chipTemperatureC = temperatureRead();
    displayStatus.boardTemperatureC = acquisitionState.board.boardTemperatureC;
    displayStatus.cpuFrequencyMhz = getCpuFrequencyMhz();
    displayStatus.speakerEnabled = speakerOn;
    displayStatus.speakerReady = speaker.ready();
    displayStatus.touchAvailable = display.touchAvailable();
    displayStatus.touchController = display.touchControllerName();
    const BoardHardwareStatus &board = acquisitionState.board;
    displayStatus.imuAvailable = board.imuAvailable;
    displayStatus.accelerationX = board.accelerationX;
    displayStatus.accelerationY = board.accelerationY;
    displayStatus.accelerationZ = board.accelerationZ;
    displayStatus.rtcAvailable = board.rtcAvailable;
    displayStatus.rtcClockValid = board.rtcClockValid;
    displayStatus.rtcDateTime = board.rtcDateTime;
    display.render(sensorReadings, currentSnapshot, displayStatus);
  }

  if (now - lastScanCounterMs >= 1000) {
    scansPerSecond = uint64_t(acquisitionState.scans-lastUiScanCount)*1000/std::max<uint32_t>(1,now-lastScanCounterMs);
    lastUiScanCount=acquisitionState.scans;
    lastScanCounterMs = now;
    checkPowerSource();
    readBatteryStatus();
  }

  if (now - lastHeartbeatMs >= configStore.get().heartbeatSeconds * 1000UL) {
    lastHeartbeatMs = now;
    sendHeartbeat();
  }

  if (now - lastDiagnosticLogMs >= kDiagnosticLogIntervalMs) {
    lastDiagnosticLogMs = now;
    recordSensorDiagnostics();
  }

  if (now - lastSdCheckMs >= kSdCheckIntervalMs) {
    lastSdCheckMs = now;
    runSdHealthCheck();
  }

  const DeviceConfig &config = configStore.get();
  if (config.configSyncEnabled && timeSynchronized &&
      (!configSyncAttemptedThisBoot || now - lastConfigSyncMs >= config.configSyncSeconds * 1000UL)) {
    syncRemoteConfiguration();
  }

  if ((lastRetentionMs == 0 && time(nullptr) > 1700000000) ||
      now - lastRetentionMs >= kRetentionIntervalMs) {
    lastRetentionMs = now;
    pruneExpiredArchives();
  }

  if (WiFi.status() != WL_CONNECTED && now - lastReconnectMs >= kReconnectIntervalMs) {
    lastReconnectMs = now;
    if (!accessPointActive) startRescueAccessPoint();
    const DeviceConfig &networkConfig = configStore.get();
    if (!networkConfig.wifiSsid.isEmpty()) {
      WiFi.disconnect(false, false);
      WiFi.mode(accessPointActive ? WIFI_AP_STA : WIFI_STA);
      if (!applyStaticNetworkConfig()) {
        logSystem("error", "invalid_static_network");
      } else {
        WiFi.setHostname(networkConfig.hostname.c_str());
        beginConfiguredStation(networkConfig);
        logSystem("info", "wifi_reconnect_started", "rescue_ap_preserved=" + boolJson(accessPointActive));
      }
    }
  }

  if (now - lastNetworkStatusMs >= kDiagnosticLogIntervalMs) {
    lastNetworkStatusMs = now;
    printNetworkStatus();
  }

  if (scheduledRestartMs != 0 && static_cast<int32_t>(now - scheduledRestartMs) >= 0) {
    delay(50);
    ESP.restart();
  }
  checkProgrammedRestart(now);
  delay(1);
}

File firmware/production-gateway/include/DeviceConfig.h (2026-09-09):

#pragma once

#include <Arduino.h>
#include <Preferences.h>

#include "ScaleCore.h"
#include "ReliabilityCore.h"

struct DeviceConfig {
  String deviceId;
  String hostname;
  String wifiSsid;
  String wifiPassword;
  bool useDhcp = true;
  String staticIp = "192.168.1.90";
  String gateway = "192.168.1.1";
  String subnet = "255.255.255.0";
  String dns = "192.168.1.1";
  String backendUrl;
  String backendToken;
  String eventHmacSecret;
  String metricsToken;
  String tlsCaCertificate;
  String tlsClientCertificate;
  String tlsClientPrivateKey;
  String notificationUrl;
  bool configSyncEnabled = false;
  String configSyncUrl;
  uint32_t configSyncSeconds = 900;
  uint32_t remoteConfigVersion = 0;
  bool mqttEnabled = false;
  String mqttHost;
  uint16_t mqttPort = 8883;
  String mqttUsername;
  String mqttPassword;
  String mqttBaseTopic = "casklogic/laveggio";
  bool mqttCommandsEnabled = false;
  String ntpServer = "pool.ntp.org";
  String timezone = "CET-1CEST,M3.5.0,M10.5.0/3";
  String adminUser = "admin";
  String adminPassword;
  bool displayDefaultOn = true;
  bool speakerDefaultOn = true;
  uint8_t speakerVolumePercent = 100;
  bool powerSenseEnabled = false;
  bool powerSenseActiveHigh = true;
  uint32_t stableWindowMs = 600;
  uint32_t heartbeatSeconds = 30;
  bool heartbeatWatchdogEnabled = false;
  uint8_t heartbeatFailureThreshold = 5;
  bool heartbeatRestartSuppressed = false;
  bool historyEnabled = true;
  bool historyKeepForever = true;
  uint16_t historyRetentionDays = 730;
  uint16_t historyFileMaxMb = 32;
  uint16_t systemLogFileMaxMb = 8;
  bool batterySenseEnabled = true;
  uint16_t batteryDividerMilli = 3000;
  uint16_t batteryMinMv = 3200;
  uint16_t batteryMaxMv = 4200;
  uint16_t batteryCapacityMah = 1000;
  String restartSchedule = "off";
  uint8_t restartHour = 3;
  uint8_t restartMinute = 0;
  uint8_t restartWeekday = 1;
  uint8_t sensorOrder[4] = {0,1,2,3};
  uint32_t calibrationRevision = 0;
  bool calibrationChecksumValid = true;
  uint8_t displayBrightness = 65;
  uint16_t displayDimSeconds = 120;
  bool displayAutoOffEnabled = false;
  uint16_t displayAutoOffMinutes = 15;
  uint8_t batteryLowPercent = 15;
  bool shutdownButtonEnabled = true;
  laveggio::ClosureConfig closure;
  laveggio::ChannelCalibration calibrations[laveggio::kChannelCount];
};

class ConfigStore {
 public:
  bool begin(const String &deviceSuffix);
  const DeviceConfig &get() const { return config_; }
  DeviceConfig &mutableConfig() { return config_; }
  bool saveSettings();
  bool saveReliabilitySettings();
  bool saveDisplayDefaultOn();
  bool saveSpeakerDefaultOn();
  bool saveSpeakerVolume();
  bool saveHeartbeatRestartSuppressed();
  bool saveRemoteConfigVersion();
  bool saveCalibration(uint8_t channel);
  bool clearCalibration(uint8_t channel);
  bool factoryReset();
  bool isProvisioned() const { return !config_.wifiSsid.isEmpty(); }

 private:
  Preferences preferences_;
  DeviceConfig config_;
  void loadCalibration();
};

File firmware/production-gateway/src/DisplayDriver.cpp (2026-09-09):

#include "DisplayDriver.h"
#include "DisplayLogo.h"

#include <SPI.h>
#include <Wire.h>
#include <algorithm>
#include <cstring>

namespace {

constexpr int kLcdMiso = -1;
constexpr int kLcdMosi = 45;
constexpr int kLcdSclk = 40;
constexpr int kLcdCs = 42;
constexpr int kLcdDc = 41;
constexpr int kLcdRst = 39;
constexpr int kLcdBacklight = 5;
constexpr int kTouchSda = 1;
constexpr int kTouchScl = 3;
constexpr int kTouchInterrupt = 4;
constexpr int kTouchReset = 2;
constexpr uint8_t kCst328Address = 0x1A;
constexpr uint8_t kCst3530Address = 0x58;
constexpr uint16_t kWidth = 240;
constexpr uint16_t kHeight = 320;

// RGB565 palette copied from the device's own web interface.
constexpr uint16_t kNavy = 0x08A4;         // #0e1520
constexpr uint16_t kBlue = 0x21CD;         // #243b6b
constexpr uint16_t kLightBlue = 0x32EF;    // #2f5e7a
constexpr uint16_t kTeal = 0x7D15;         // #7fa3ae
constexpr uint16_t kWhite = 0xFFFF;
constexpr uint16_t kText = 0x1926;         // #1a2430
constexpr uint16_t kSurface = 0xF7BF;      // #f5f7fa
constexpr uint16_t kSurfaceBlue = 0xFFFF;  // #ffffff
constexpr uint16_t kBorder = 0xDF1D;       // #d9e2ea
constexpr uint16_t kMuted = 0x5B2E;        // #586776
constexpr uint16_t kGreen = 0x2C4A;        // #2e8b57
constexpr uint16_t kGreenLight = 0x7D15;   // #7fa3ae
constexpr uint16_t kGreenSurface = 0xEFBD; // #eaf4ee
constexpr uint16_t kAmber = 0xD443;        // #d18a1d
constexpr uint16_t kAmberSurface = 0xFFBC; // #fff5e6
constexpr uint16_t kRed = 0xCA69;
constexpr uint16_t kRedSurface = 0xFF7D;   // #fceced

const uint8_t *glyphFor(char value) {
  static const uint8_t blank[5] = {0, 0, 0, 0, 0};
  static const uint8_t dash[5] = {0x08, 0x08, 0x08, 0x08, 0x08};
  static const uint8_t dot[5] = {0x00, 0x60, 0x60, 0x00, 0x00};
  static const uint8_t slash[5] = {0x60, 0x18, 0x06, 0x01, 0x00};
  static const uint8_t colon[5] = {0x00, 0x36, 0x36, 0x00, 0x00};
  static const uint8_t percent[5] = {0x63, 0x13, 0x08, 0x64, 0x63};
  static const uint8_t digits[10][5] = {
    {0x3E, 0x51, 0x49, 0x45, 0x3E}, {0x00, 0x42, 0x7F, 0x40, 0x00},
    {0x42, 0x61, 0x51, 0x49, 0x46}, {0x21, 0x41, 0x45, 0x4B, 0x31},
    {0x18, 0x14, 0x12, 0x7F, 0x10}, {0x27, 0x45, 0x45, 0x45, 0x39},
    {0x3C, 0x4A, 0x49, 0x49, 0x30}, {0x01, 0x71, 0x09, 0x05, 0x03},
    {0x36, 0x49, 0x49, 0x49, 0x36}, {0x06, 0x49, 0x49, 0x29, 0x1E}
  };
  static const uint8_t letters[26][5] = {
    {0x7E, 0x11, 0x11, 0x11, 0x7E}, {0x7F, 0x49, 0x49, 0x49, 0x36},
    {0x3E, 0x41, 0x41, 0x41, 0x22}, {0x7F, 0x41, 0x41, 0x22, 0x1C},
    {0x7F, 0x49, 0x49, 0x49, 0x41}, {0x7F, 0x09, 0x09, 0x09, 0x01},
    {0x3E, 0x41, 0x49, 0x49, 0x7A}, {0x7F, 0x08, 0x08, 0x08, 0x7F},
    {0x00, 0x41, 0x7F, 0x41, 0x00}, {0x20, 0x40, 0x41, 0x3F, 0x01},
    {0x7F, 0x08, 0x14, 0x22, 0x41}, {0x7F, 0x40, 0x40, 0x40, 0x40},
    {0x7F, 0x02, 0x0C, 0x02, 0x7F}, {0x7F, 0x04, 0x08, 0x10, 0x7F},
    {0x3E, 0x41, 0x41, 0x41, 0x3E}, {0x7F, 0x09, 0x09, 0x09, 0x06},
    {0x3E, 0x41, 0x51, 0x21, 0x5E}, {0x7F, 0x09, 0x19, 0x29, 0x46},
    {0x46, 0x49, 0x49, 0x49, 0x31}, {0x01, 0x01, 0x7F, 0x01, 0x01},
    {0x3F, 0x40, 0x40, 0x40, 0x3F}, {0x1F, 0x20, 0x40, 0x20, 0x1F},
    {0x3F, 0x40, 0x38, 0x40, 0x3F}, {0x63, 0x14, 0x08, 0x14, 0x63},
    {0x07, 0x08, 0x70, 0x08, 0x07}, {0x61, 0x51, 0x49, 0x45, 0x43}
  };
  if (value >= '0' && value <= '9') return digits[value - '0'];
  if (value >= 'a' && value <= 'z') value -= 32;
  if (value >= 'A' && value <= 'Z') return letters[value - 'A'];
  if (value == '-') return dash;
  if (value == '.') return dot;
  if (value == '/') return slash;
  if (value == ':') return colon;
  if (value == '%') return percent;
  return blank;
}

}  // namespace

void DisplayDriver::command(uint8_t value) {
  SPI.beginTransaction(SPISettings(80000000, MSBFIRST, SPI_MODE0));
  digitalWrite(kLcdCs, LOW);
  digitalWrite(kLcdDc, LOW);
  SPI.transfer(value);
  digitalWrite(kLcdCs, HIGH);
  SPI.endTransaction();
}

void DisplayDriver::data(uint8_t value) {
  SPI.beginTransaction(SPISettings(80000000, MSBFIRST, SPI_MODE0));
  digitalWrite(kLcdCs, LOW);
  digitalWrite(kLcdDc, HIGH);
  SPI.transfer(value);
  digitalWrite(kLcdCs, HIGH);
  SPI.endTransaction();
}

void DisplayDriver::setWindow(uint16_t x, uint16_t y, uint16_t width, uint16_t height) {
  const uint16_t x1 = x + width - 1;
  const uint16_t y1 = y + height - 1;
  command(0x2A);
  data(x >> 8); data(x); data(x1 >> 8); data(x1);
  command(0x2B);
  data(y >> 8); data(y); data(y1 >> 8); data(y1);
  command(0x2C);
}

void DisplayDriver::fillRect(uint16_t x, uint16_t y, uint16_t width, uint16_t height, uint16_t color) {
  if (x >= kWidth || y >= kHeight || width == 0 || height == 0) return;
  width = std::min<uint16_t>(width, kWidth - x);
  height = std::min<uint16_t>(height, kHeight - y);
  setWindow(x, y, width, height);
  SPI.beginTransaction(SPISettings(80000000, MSBFIRST, SPI_MODE0));
  digitalWrite(kLcdCs, LOW);
  digitalWrite(kLcdDc, HIGH);
  const uint8_t high = color >> 8;
  const uint8_t low = color;
  for (uint32_t index = 0; index < static_cast<uint32_t>(width) * height; ++index) {
    SPI.transfer(low); SPI.transfer(high);
  }
  digitalWrite(kLcdCs, HIGH);
  SPI.endTransaction();
}

void DisplayDriver::fillCard(uint16_t x, uint16_t y, uint16_t width, uint16_t height, uint16_t color) {
  fillRect(x + 3, y, width - 6, height, color);
  fillRect(x + 1, y + 2, width - 2, height - 4, color);
  fillRect(x, y + 4, width, height - 8, color);
}

void DisplayDriver::drawLogo(uint16_t x, uint16_t y) {
  setWindow(x, y, DISPLAY_LOGO_WIDTH, DISPLAY_LOGO_HEIGHT);
  SPI.beginTransaction(SPISettings(80000000, MSBFIRST, SPI_MODE0));
  digitalWrite(kLcdCs, LOW);
  digitalWrite(kLcdDc, HIGH);
  for (uint16_t index = 0; index < DISPLAY_LOGO_WIDTH * DISPLAY_LOGO_HEIGHT; ++index) {
    const uint8_t bit = 1U << (7 - index % 8);
    const bool navy = (pgm_read_byte(DISPLAY_LOGO_NAVY + index / 8) & bit) != 0;
    const bool teal = (pgm_read_byte(DISPLAY_LOGO_TEAL + index / 8) & bit) != 0;
    const uint16_t pixel = teal ? kTeal : (navy ? kBlue : kSurface);
    SPI.transfer(pixel); SPI.transfer(pixel >> 8);
  }
  digitalWrite(kLcdCs, HIGH);
  SPI.endTransaction();
}
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

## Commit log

2026-08-28 Organize ESP32 scale reader and document project
2026-08-28 Add Amazon links for prototype hardware
2026-08-28 Add licensed 3D-print enclosure files
2026-08-29 Implement ESP32-C6 production gateway
    [partitions.csv]
2026-08-29 Secure gateway and expand device management
2026-08-29 Document 5V boost charger wiring
2026-08-29 Increase OTA partition headroom
    [partitions.csv]
2026-08-31 Improve network recovery and sensor diagnostics
2026-08-31 Add secure OTA flow and multipage device display
2026-09-03 Port gateway to Waveshare ESP32-S3 touch display
    [partitions_s3.csv]
2026-09-04 Update hardware BOM and non-fiscal usage notice
2026-09-04 Remove PesaLink traceability tagline
2026-09-04 Fix board startup audio and SD support
    [DisplayDriver.cpp, DisplayDriver.h, SpeakerDriver.cpp]
2026-09-04 Match device UI palette and hard-stop audio
2026-09-04 Fix display color byte order and add audio volume
    [DeviceConfig.h, DisplayDriver.cpp, SpeakerDriver.cpp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]
2026-09-04 Prevent stale web assets from breaking volume control
    [main.cpp]
2026-09-05 Update installed hardware materials and antenna procedure
2026-09-05 Add 3D printing timelapse videos
2026-09-05 Document heat-set inserts for sensor supports
2026-09-06 Add printable models and prototype photos
    [boccola-calamita-v4.stl, esp32-s3-touch-lcd-2_8-v01.stl, pesalink-v2.3mf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]
2026-09-06 Stabilize Wi-Fi setup and add display auto-off
    [DeviceConfig.h, DisplayDriver.cpp, DisplayDriver.h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]
2026-09-06 Fix physical reset countdown and display wake
    [DisplayDriver.cpp, DisplayDriver.h, main.cpp]
2026-09-06 Keep factory reset on BOOT only
    [DisplayDriver.cpp, DisplayDriver.h, main.cpp]
2026-09-07 Fix PesaLink heartbeat panic and AP selection
    [main.cpp]
2026-09-08 fix(firmware): allinea sensori e moltiplicatori
    [main.cpp]
2026-09-08 fix(firmware): incrementa versione a 2.2.5
    [main.cpp]
2026-09-09 fix(pesalink): restore full speed and streamline maintenance
    [DeviceConfig.h, main.cpp]
